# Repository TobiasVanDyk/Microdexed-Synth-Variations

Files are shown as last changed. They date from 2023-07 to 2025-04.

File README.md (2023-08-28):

# Microdexed and Minidexed Synth Variations

Variations of the Microdexed FM Synth by [**Codeberg-dcoredump**](https://codeberg.org/dcoredump/MicroDexed) - using a PCM5102A module, and 6N137 for the Midi input, and Microdexed Touch FM Synth by [**Codeberg-positionhigh**](https://codeberg.org/positionhigh/MicroDexed-touch) - it replaced the 2.8 inch LCD with a 3.2 inch sized LCD, used full-sized Midi in and out sockets, and a 6N137 for the Midi input.

In addition four Circle-based Raspberry Pi synths were made: Three Raspberry Pi 3B+ and 3B synth variations of the **miniDexed FM Synth** (which is an 8 x DX7) synth, by [**Probonopd**](https://github.com/probonopd/MiniDexed), two using a using a Waveshare WM8960 DAC Hat and one with a PCM5102A DAC module, and all three with a 6N137 MidiIn DIN socket, and one with a Pico PC USBMidi Interface. A fourth **MT32-Pi** synth using a Raspberry 3A+ and WM8960 DAC was assembled on a breadboard.

The [**Zynthian Open Synth Platform**](https://zynthian.org/) also use both the [**Dexed**](https://zynthian.org/engines/_engine-list/engine-dexed) (Microdexed and Minidexed) and [**Fluidsynth**](https://zynthian.org/engines/_engine-list/engine-fluidsynth) (MT32-Pi) synth engines, but is based on a more traditional low-latency, almost RT, operating system, similar to [**Patchbox OS**](https://blokas.io/patchbox-os/).
 
<p align="left">
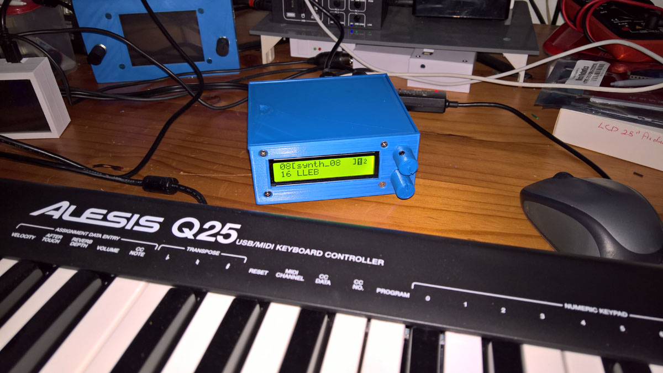
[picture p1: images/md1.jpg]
 
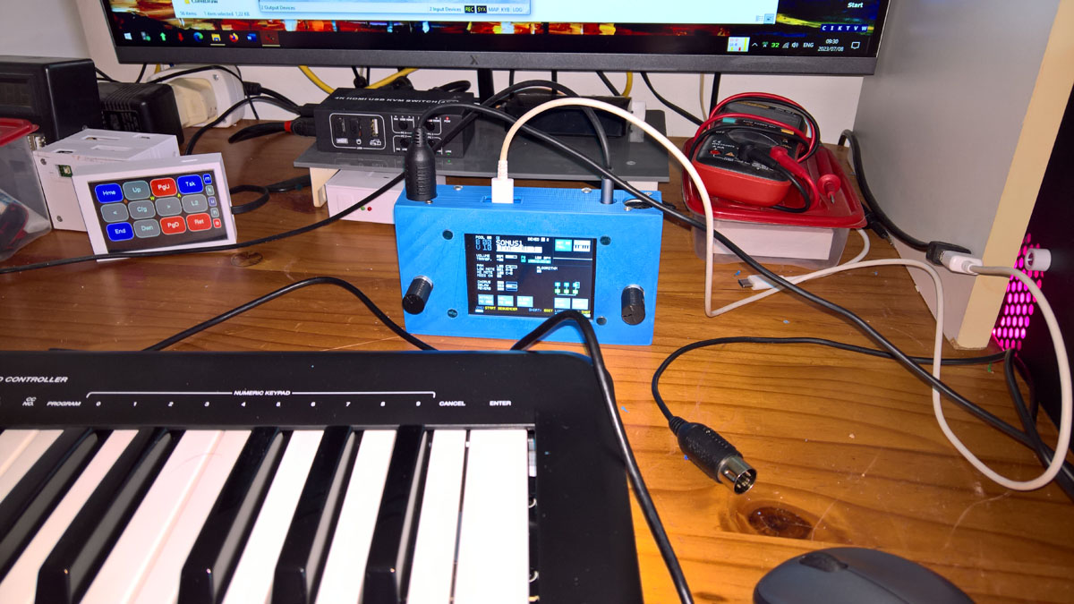
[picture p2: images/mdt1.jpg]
 
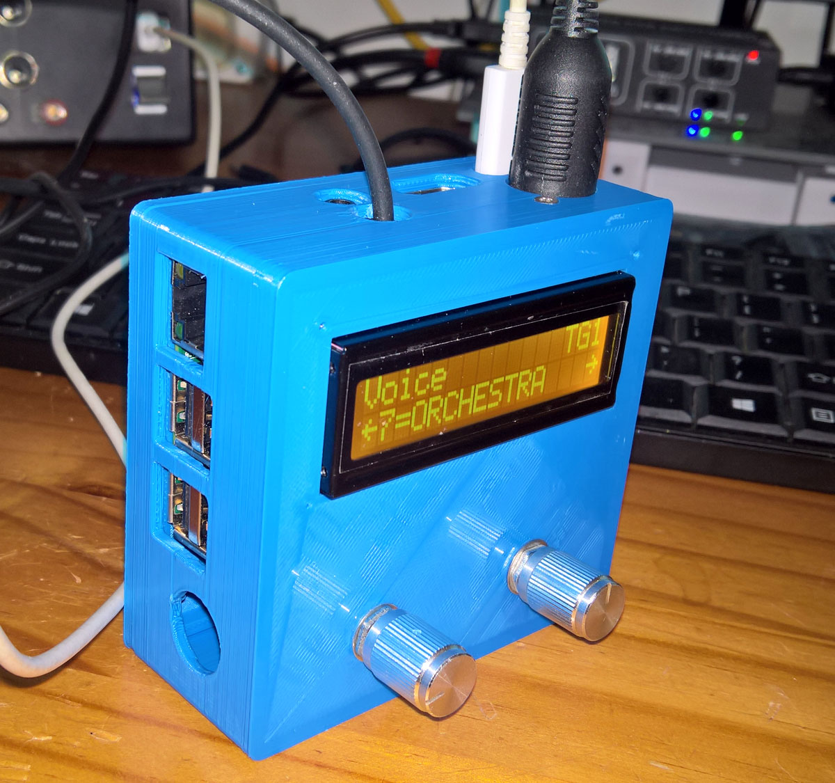
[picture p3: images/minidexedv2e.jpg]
  
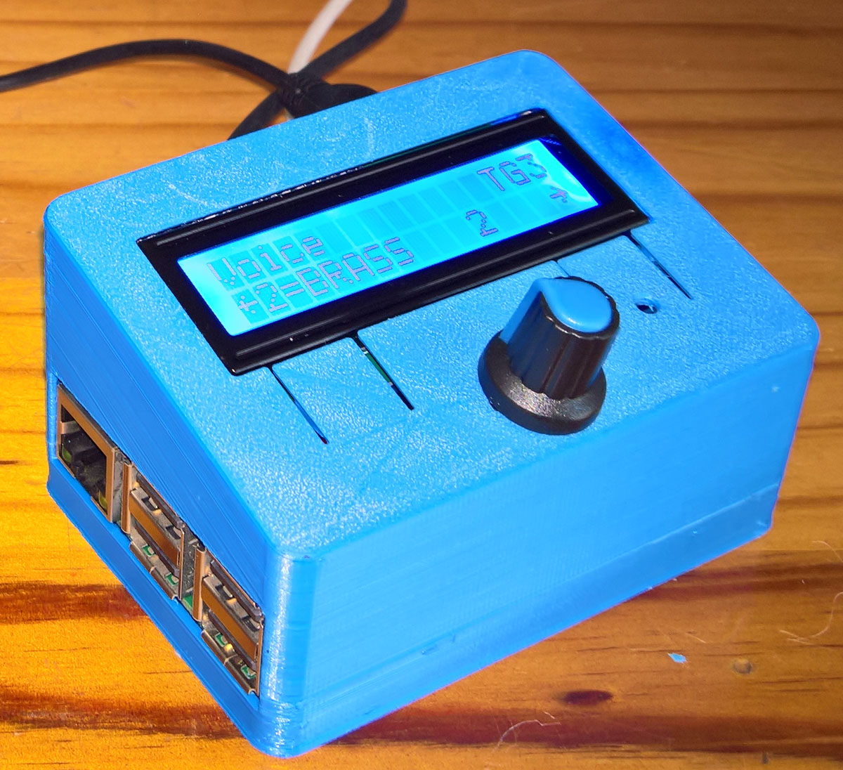
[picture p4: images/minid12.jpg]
  
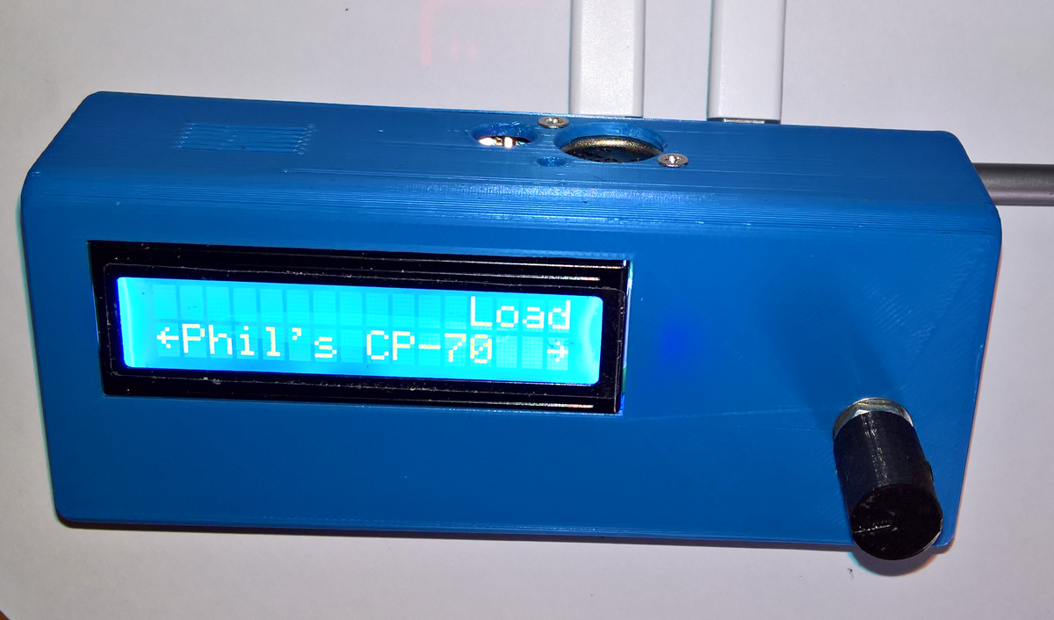
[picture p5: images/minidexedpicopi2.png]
    
</p>

* [**Microdexed FM Synth Teensy 3.6 Variation**](Microdexed1)

* [**MicrodexedTouch FM Synth Teensy 4.1 Variation**](Microdexed2)

* [**Microdexed FM Synth Teensy 4.0 and Teensy 4.1 Dev-branch Variation**](Microdexed3)

* [**Minidexed FM and MT32-Pi Raspberry Pi 3B+ and 3A+ and WM8960 DAC Circle-based Synths**](Minidexed1)

* [**Compiling Minidexed under WSL2 (Ubuntu 20.04) on Windows 11**](https://github.com/TobiasVanDyk/Microdexed-Synth-Variations/tree/main/Minidexed1/Minidexed-compile-WSL2-Win11)

* [**Minidexed Raspberry Pi 3B and Pico RP2040 USBMidi Interface and PCM5102A DAC Synth**](Minidexed2)

* [**Pico RP2040 USBMidi PC Interfaces for the Minidexed Synth**](PicoUSBMidi-PCInterface)

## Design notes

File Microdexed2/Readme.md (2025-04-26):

# Microdexed-Touch: Teensy 4.1 - PCM5102A DAC - 3.2inch ILI9341 Resistive Touch LCD - 6N137 Midi-In

This is a variation of the Microdexed Touch FM Synth (Yamaha-DX7) by [**Codeberg-positionhigh**](https://codeberg.org/positionhigh/MicroDexed-touch). It replaced the capactive touch 3.2 inch LCD with a resistive touch LCD, uses full-sized Midi in and out sockets with a 6N137 for the Midi input. Compiled versions 1.9.8.7 (16 MB PSRAM) and 1.7.1 (8 MB PSRAM 16 MB Flash), firmware was used. 

Both firmware versions are shown below, the stripboard layout for both are the same as only the Flash module is removed from its socket on the stripboard, and a second 8MB PSRAM module was soldered on the back of the Teensy 4.1. The .hex firmware for the two versions are in the folders PSRAM8-Flash-v171 and PSRAM16-v1987. Replace platformio.ini and config.h with those included in the folders if new versions are compiled.

The stripboard Fritzing layout is included here, as are the case 3d-files. Refer to the photo included in the [**issue here**](https://github.com/TobiasVanDyk/STM32F411-PCM5102A-24bit-USB-Audio-DAC/issues/2) for how to bridge three of the DAC module option pads.

The older schematic for a resistive touch LCD is shown below for the new schematic refer to the [**March 2025 build manual**](https://codeberg.org/positionhigh/MicroDexed-touch/wiki/BUILD-AND-USER-MANUAL)

<p align="left">
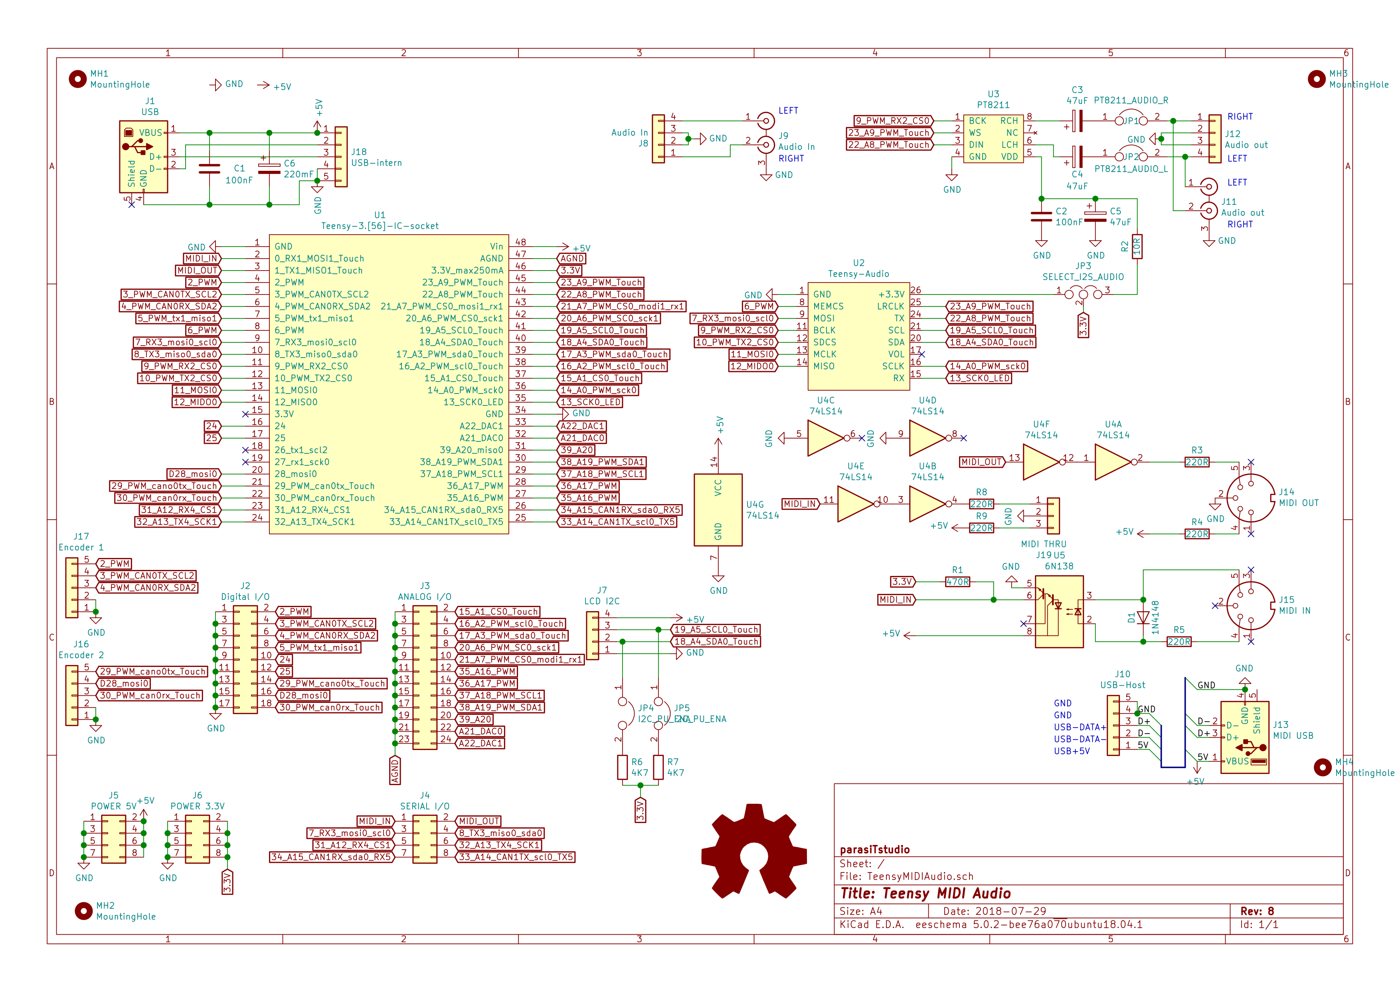
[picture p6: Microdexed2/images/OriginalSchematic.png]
 
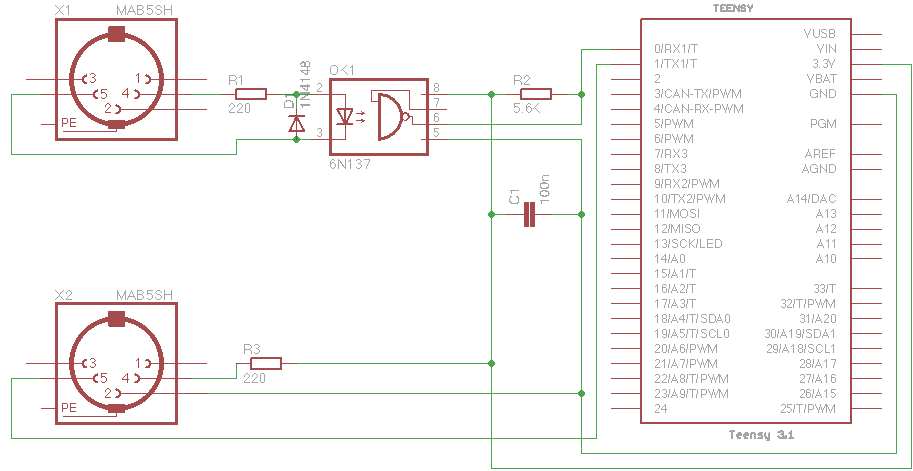
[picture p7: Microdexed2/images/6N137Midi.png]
 
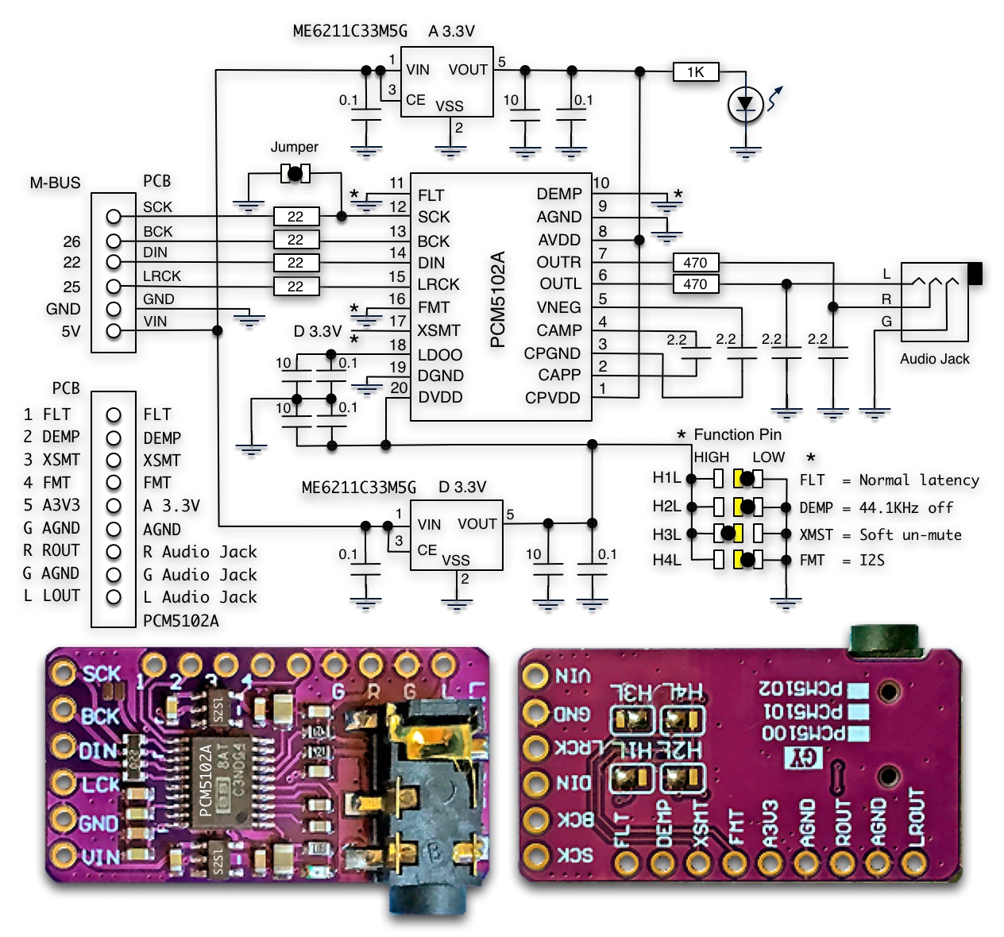
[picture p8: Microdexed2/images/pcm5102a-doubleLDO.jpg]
 
</p>

<p align="left">
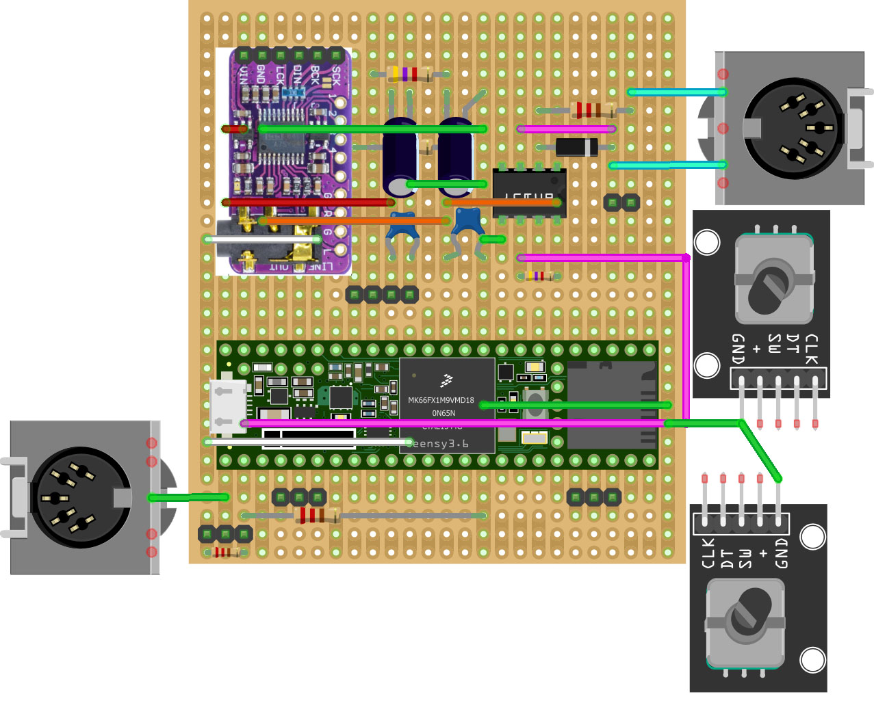
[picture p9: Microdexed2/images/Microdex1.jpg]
 
 
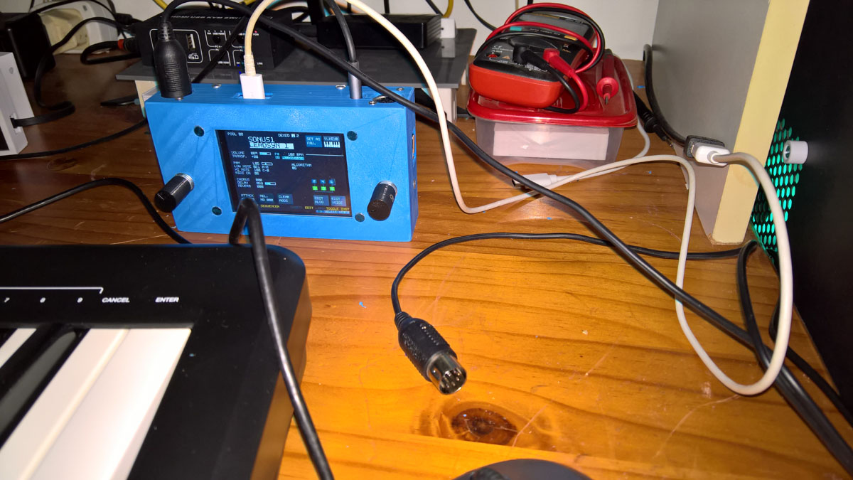
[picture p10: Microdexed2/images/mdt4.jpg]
 
</p>

<p align="left">
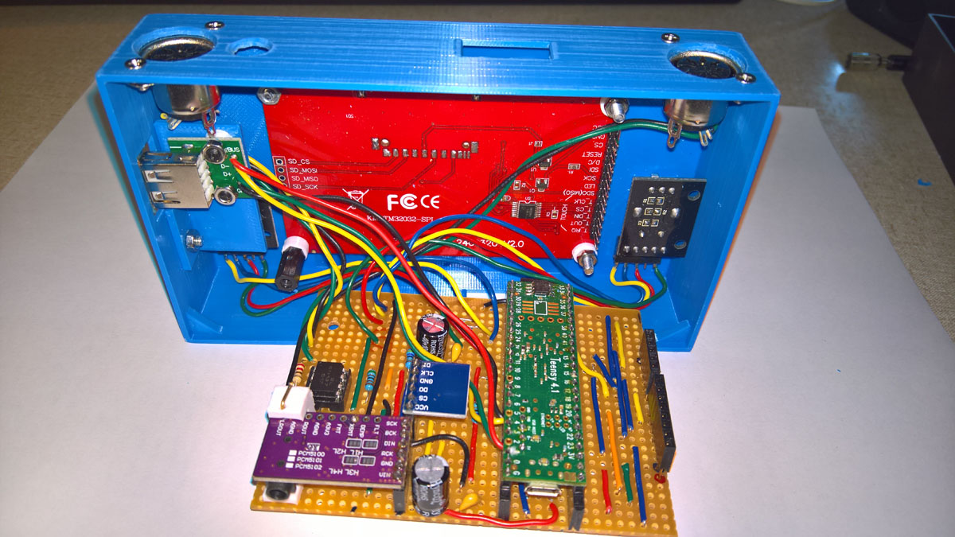
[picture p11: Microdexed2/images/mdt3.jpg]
 
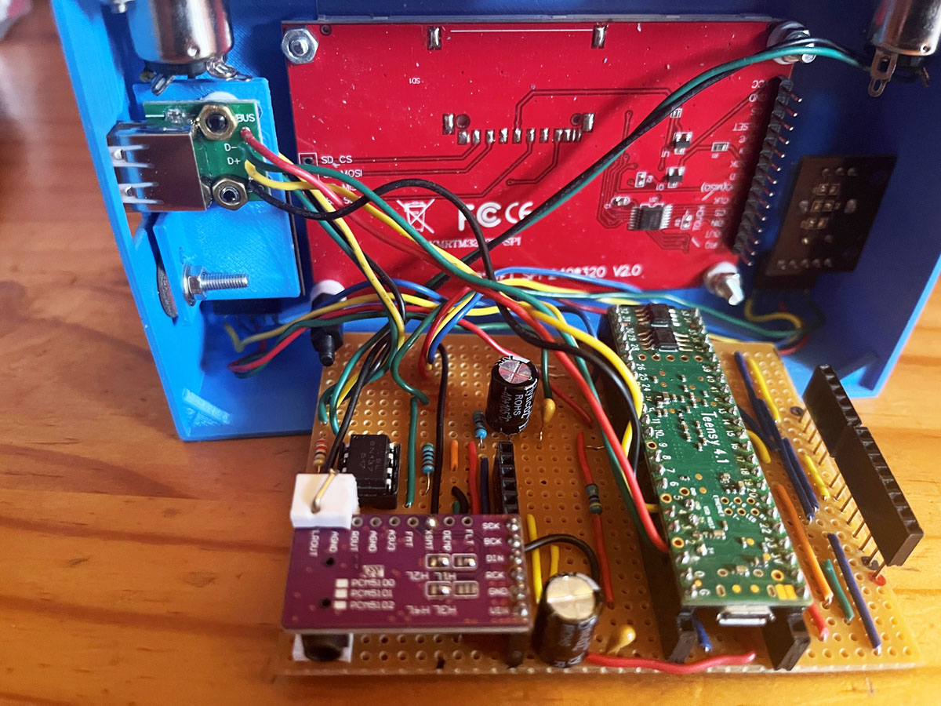
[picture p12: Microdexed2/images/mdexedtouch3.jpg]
 
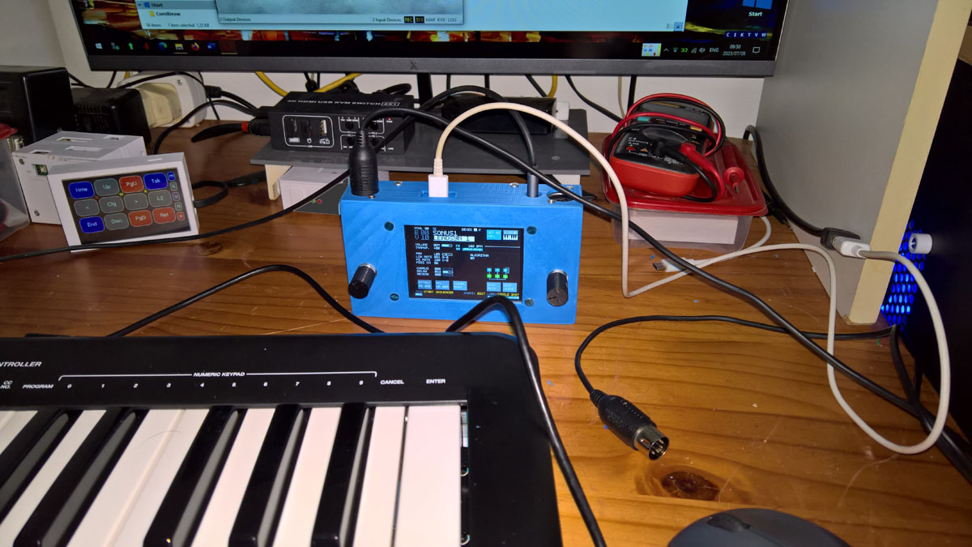
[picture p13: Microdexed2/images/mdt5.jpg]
 
</p>

Note the warning when [**using i2c Backpacks with 5v LCD displays and 3v3 MCU's or Raspberry Pi's**](https://github.com/TobiasVanDyk/Microdexed-Synth-Variations/tree/main/i2cbackpack)

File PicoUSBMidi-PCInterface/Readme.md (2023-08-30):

## Pico RP2040 as USB Midi PC Interface for the Raspberry Pi Minidexed

Three different PC USB-Midi Interfaces were compiled and tested as a means to connect the Minidexed RaspberryPi 3B to a PC as a Midi Synth device. Two are Pico-SDK-based and the third is Arduino IDE-based. All three worked well and will be expanded on in the future. Currently the neatly-coded Midi-Adapter by rsta2 is installed in the Minidexed Synth referred to here as Minidexed2.

* **USB-Midi Interfaces 1 and 2:** These are Pico SDK-based and are from the same [**rsta2 Github**](https://github.com/rsta2/pico) as the Circle libraries. Both were compiled on Windows 10 using the [**instructions available here**](https://github.com/TobiasVanDyk/Pico-MCU-from-Raspberry-Pi/blob/main/Install-Pico-SDK-in-Windows10x64-May-2023.pdf), and both the build directories and the uf2 files are here as Midi-Adaptor.zip. Both interfaces were connected using the Pico's UART0-TX (Pin1) and 3v3 (Pin36) via two 47ohm resistors to a 6N137 optical 5Pin Midi DIN input (in turn connected the the Raspberry Pi's Rx pin). Alternatively they were connected via the Pico GND (Pin3) and TX0 (Pin1) directly to the raspberry Pi's RX Pin. Midi-Ox shows Midi-Adaptor-Flex as having one input and one output - refer to the picture below. (The Um ONE adapter is a Roland UM-One Mk2)

* **USB-Midi Interface 3:** This is [**based on the discussion here**](https://www.reddit.com/r/raspberrypipico/comments/11w8f29/multiple_virtual_usb_midi_cables_using_arduino_ide/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), and the code presented there were compiled using the Earle-Philhower Arduino IDE setup. The ino and uf2 files are here as DualInOutUSBMidi.zip. This is still a WIP and will be looked at in more detail later, but it is is working with the Minidexed Synth. Midi-Ox shows it as having two inputs and two outputs - refer to the picture below. Both inputs were tested with the Minidexed Raspberry Pi using TX0 and TX1 respectively ie. connected to the Minidexed through the Pico's TX0 (Pin1) and TX1 (Pin6) and 3v3 using 47ohm resistors on both wires. 

There are two ways to connect the Pico to the Minidexed Raspberry Pi. The first is through the (added) Midi optical 6N137 interface using the Pico TX (Pin1) and 3v3 (Pin36) Pins via two 47ohm resistors. The second is to connect the Pico TX0 and Ground directly to the Raspberry Pi's RX (Pin10) and Ground (Pin6) connection. The latter option is used here and a SPDT switch selects between the 6N137-Midi or the Pico-USBMidiPC input to the Minidexed Synth. The picture below shows the Pico USMMidi Interface installed in the Minidexed2, inbetween the PCM5102A DAC modile abd 6N137 Midi-Input on the left, and the Raspberry Pi 3B on the right. Currently the Pico and Raspberry Pi are independantly powered but if the Pico is permantly used the Raspberry Pi could be powered from the Pico's VSys 5v pin. 

<p align="left">
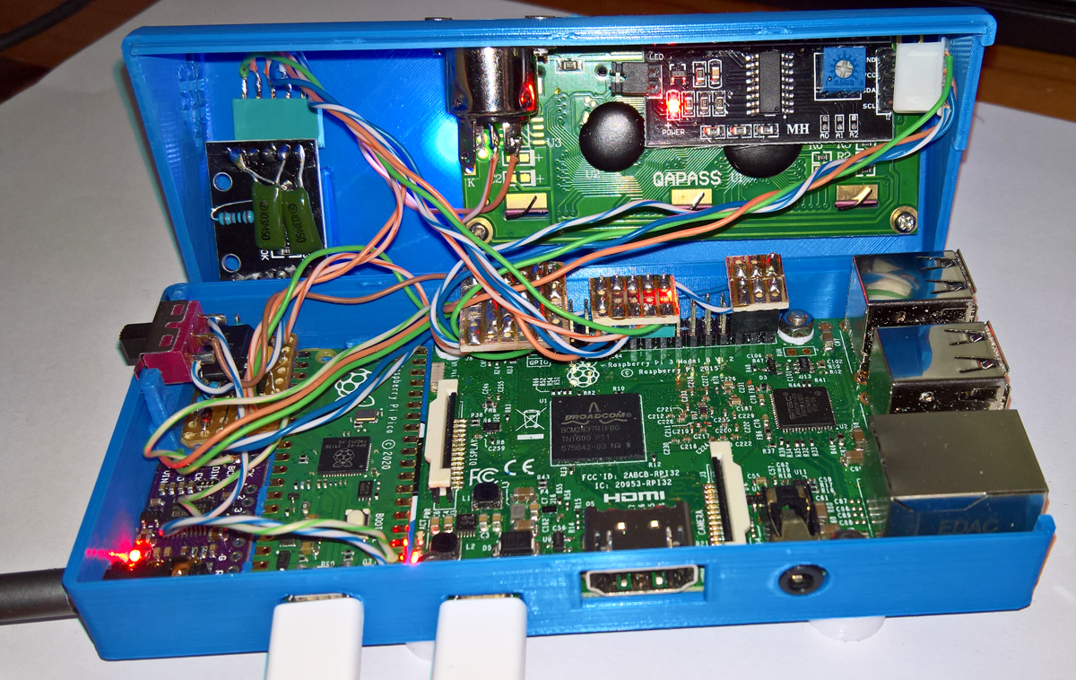
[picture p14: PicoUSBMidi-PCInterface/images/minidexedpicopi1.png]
 
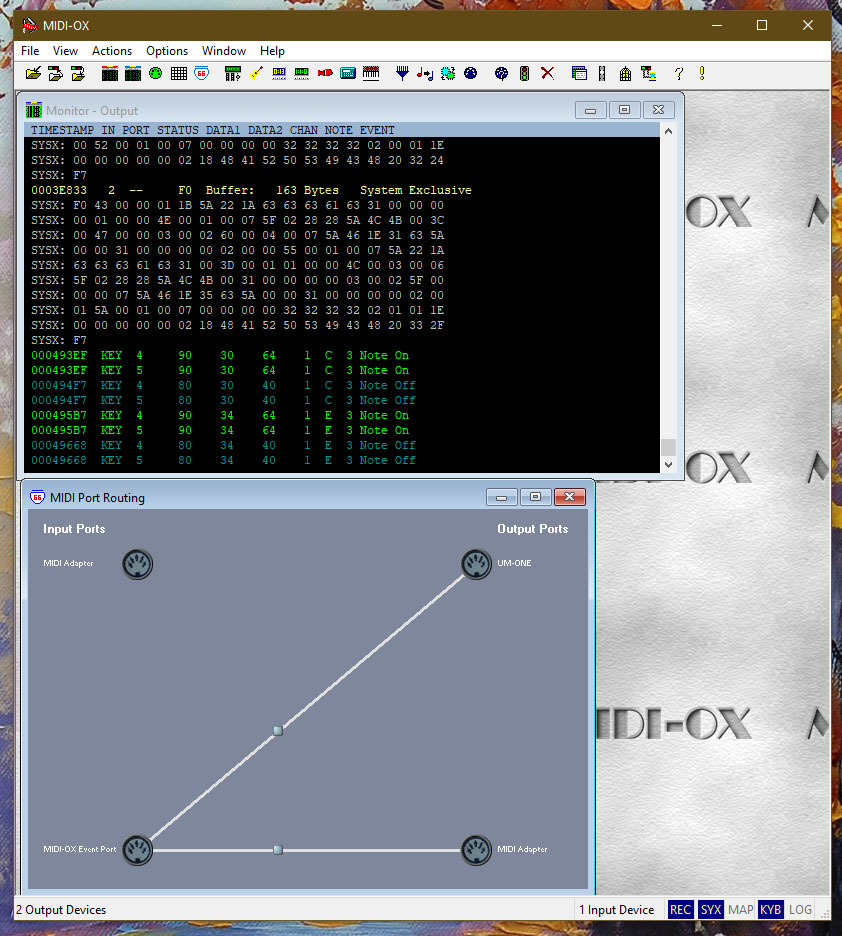
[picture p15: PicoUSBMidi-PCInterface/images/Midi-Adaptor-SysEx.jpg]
 
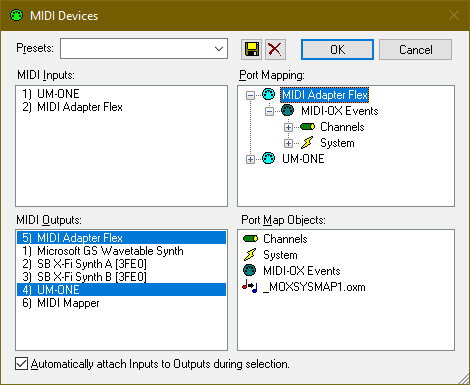
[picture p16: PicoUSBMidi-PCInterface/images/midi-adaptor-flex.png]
 
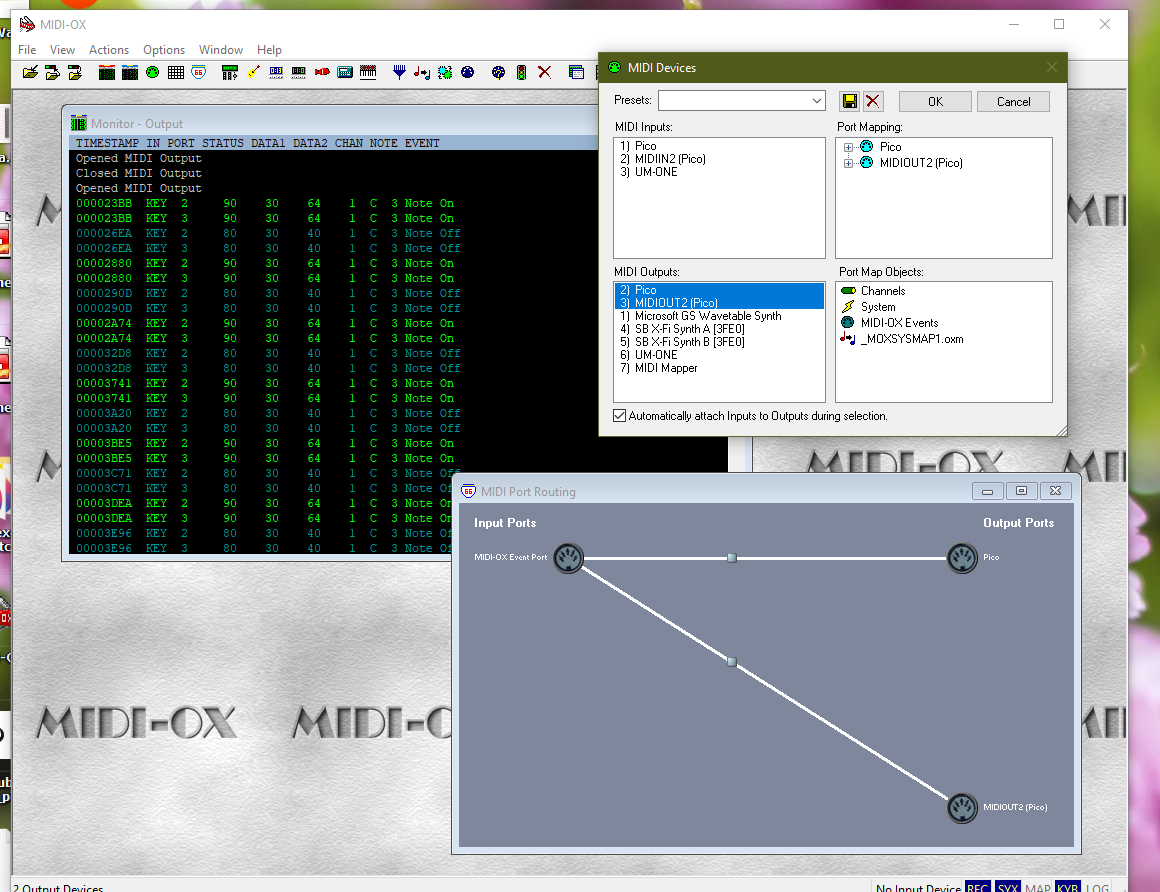
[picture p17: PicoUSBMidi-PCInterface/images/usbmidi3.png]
 
</p>

There is also an fourth option to use Circuitpython the make the Pico-based Midi interface - this was not tested but is [**discussed here**](https://github.com/alf45tar/PedalinoMini) just after the rsta2 SDK -based interface. [**This site has many Pico Midi interface and router projects**](https://diyelectromusic.wordpress.com/) mainly using Circuitpython. 

Another site use a Pico USB Host to bridge a modern USB MIDI device such as a Midi Music keyboard to a 5-pin DIN MIDI IN and MIDI OUT - [**midi2usbhost**](https://github.com/rppicomidi/midi2usbhost), and a Pc USB to 5-pin DIN MIDI interface - [**midi2usbdev**](https://github.com/rppicomidi/midi2usbdev), also using a Pico. This has not been tested as yet.

* **SDK compile instructions:** Download [**rsta2 Pico**](https://github.com/rsta2/pico) as a zip file and extract under your Pico development folder as a folder pico. Open a Developer Command Prompt Window (Visual Studio Shell) as administrator, and (for example) run: setx PICO_SDK_PATH "C:\Users\Pico\Downloads\pico-sdk" or wherever your own Pico SDK is situated. Then do:
 
``` 
cd pico
mkdir build
cd build
cmake -G "NMake Makefiles" ..
nmake
``` 

This will build all four of the example projects - the uf2 files are inside the build directories.

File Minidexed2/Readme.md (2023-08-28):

# Minidexed with Pico USBMidi Interface for a Minidexed Raspberry Pi 3B

**This is a Minidexed with Raspberry Pi 3B using a PCM5102A module, a Pico RP2040 PC USBMidi-Interface, and a 6N137 Midi 5pin DIN Input**

This is another variation of the Minidexed DX7-Synth by [**Probonopd**](https://github.com/probonopd/MiniDexed) and [**Circle**](https://github.com/rsta2/circle) which runs the RPi as a if it is an MCU. 

It uses the excellent [**snap-close**](images/DHSbuild.png) 3d-printed case [**presented by dhstsw here**](https://github.com/probonopd/MiniDexed/discussions/165), and the top and modified bottom (the trimpot was replaced with a [**6N137 Midi Interface**](6N137Midi.png) and a 5pin DIN socket added) STL files are in the STL folder. The modified case here is still a WIP. 

The Pico and Minidexed Tx-Rx Midi interface is [**discussed here**](https://github.com/TobiasVanDyk/Microdexed-Synth-Variations/tree/main/PicoUSBMidi-PCInterface).

<p align="left">
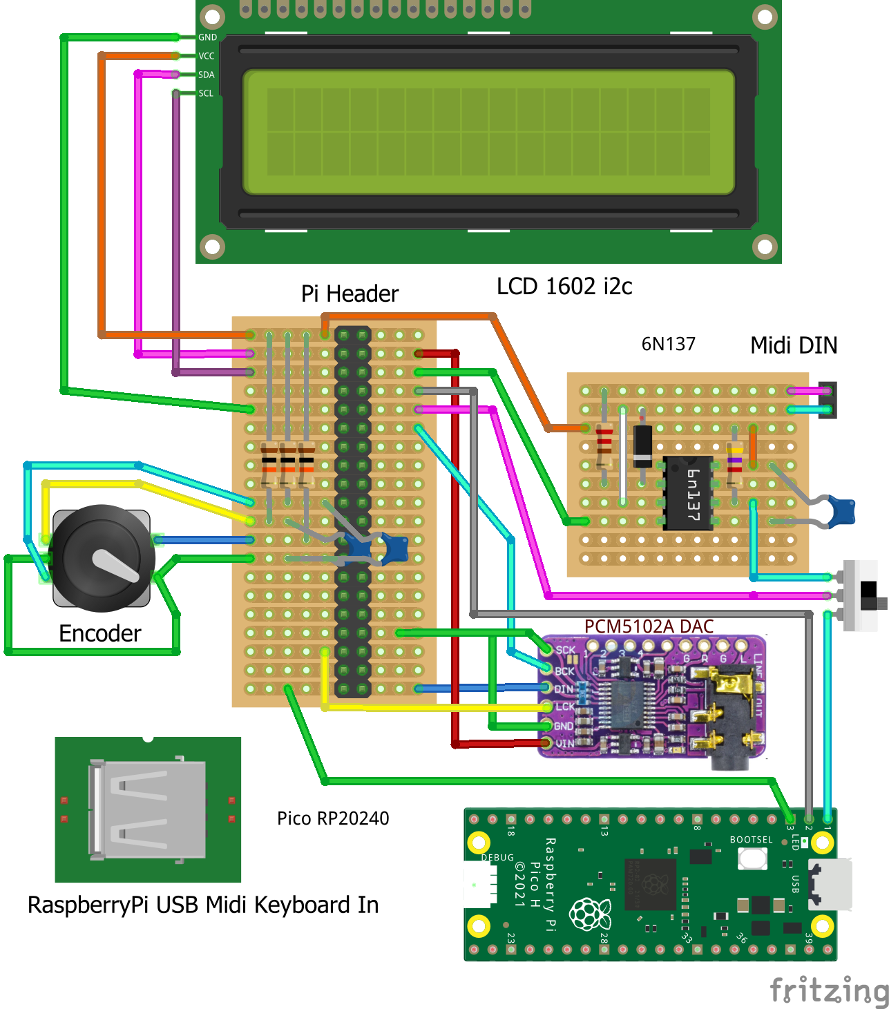
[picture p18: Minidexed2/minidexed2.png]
   
 
 
</p>

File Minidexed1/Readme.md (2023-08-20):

# Minidexed with Raspberry Pi 3B+ and MT32-Pi with a Raspberry Pi 3A+

## Minidexed with Raspberry Pi 3B+ using a Waveshare WM8960 DAC hat and a 6N137 MidiIn
This is variation of the Minidexed 8xDX7 (Yamaha-DX7-Synth) by [**Probonopd**](https://github.com/probonopd/MiniDexed) and [**Circle**](https://github.com/rsta2/circle) which runs the RPi as a if it is an MCU. (Circle is a C++ bare metal programming environment for the Raspberry Pi - i.e. it is not a RTOS.)

Two case variations were used. The first used the the snap-close 3d-case made available at the Github Minidexed site, and the second was based on a [**Minidexed case**](https://github.com/probonopd/MiniDexed/discussions/165) by [**RomixNL on Thingiverse**](https://www.thingiverse.com/thing:5371115). The STL files for the modified RomixNL case are in the STL folder here. The second rotary encoder present in the the second case will be used as a volume control and mute (all notes off) control.

In both cases two changes were made: (1) This uses the i2s + i2c [**Waveshare WM8960 DAC**](https://www.waveshare.com/wm8960-audio-hat.htm) as [**discussed here**](https://github.com/TobiasVanDyk/RaspberryPi-GPIO-Audio) and [**here**](https://github.com/TobiasVanDyk/Wolfson-WM8960-Arduino-Teensy-Driver), and sounds great. (2) A [**DIN 6N137 Midi-In**](images/6N137Midi.png) was also added. A list of the [**hardware and build intructions**](https://github.com/probonopd/MiniDexed/wiki/Hardware) are presented in detail on the Minidexed Github. 

The Minidexed can be used as a USB Midi host i.e. it can play via a Midi USB keyboard plugged into the Minidexed Raspberry Pi USB ports, but needs something such as a ATMega32U4 (Arduino Pro Micro) or RPi Pico, to act as a a USB Midi device i.e. appear to a PC as a [**USB Midi device**](https://github.com/probonopd/MiniDexed/discussions/236).

It should be noted that the 3v3 regulator on the Pi3B(+)/4B can easily supply the 1602LCD current (about 80mA) - refer to [**this discussion**](https://raspberrypi.stackexchange.com/questions/51615/raspberry-pi-power-limitations) where a value of 800mA maximum for the 3v3 supply is suggested.

<p align="left">
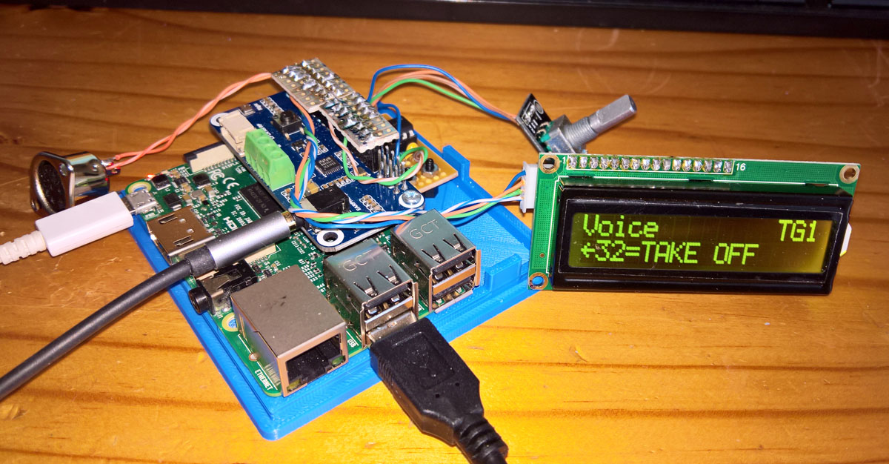
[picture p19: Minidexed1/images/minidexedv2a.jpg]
 
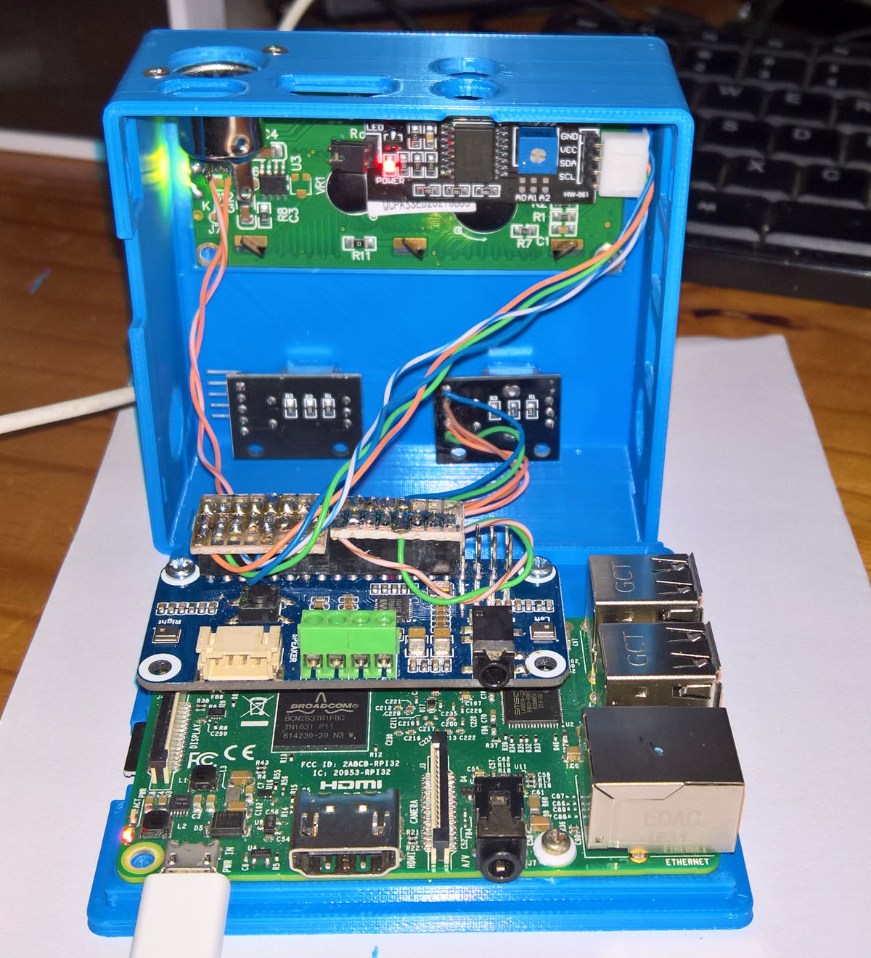
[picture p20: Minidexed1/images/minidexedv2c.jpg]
 
</p>

<p align="left">
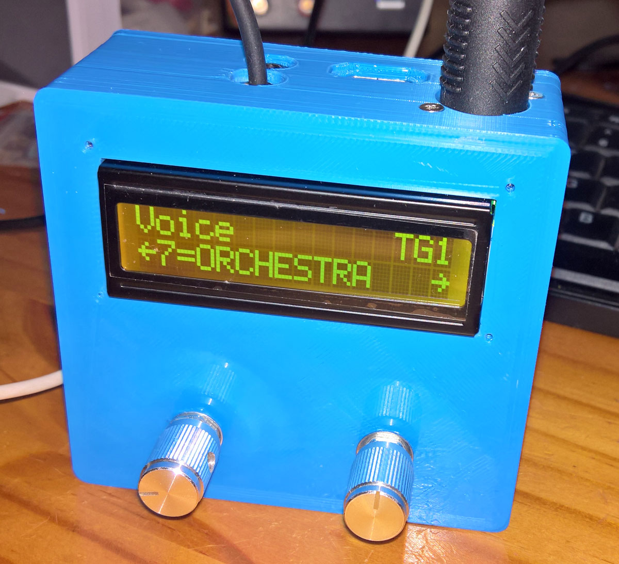
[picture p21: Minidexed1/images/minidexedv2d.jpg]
 
 
</p>

<p align="left">
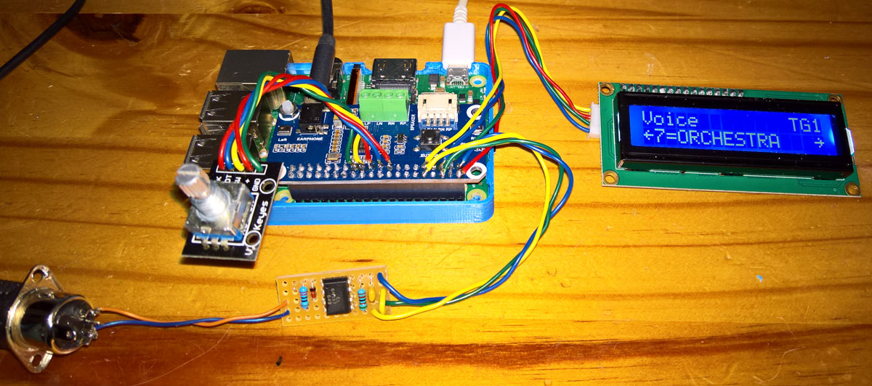
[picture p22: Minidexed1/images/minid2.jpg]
 
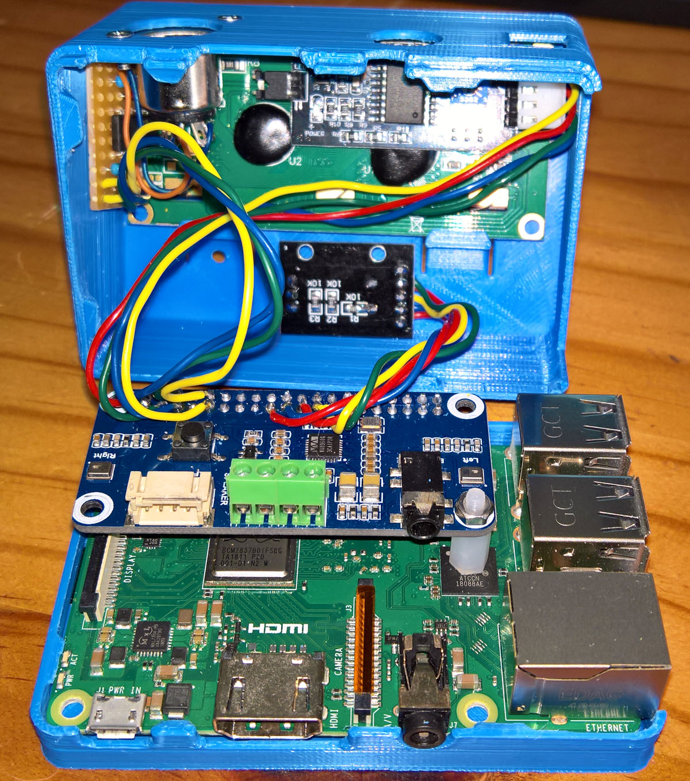
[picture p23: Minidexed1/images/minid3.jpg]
 
</p>

<p align="left">
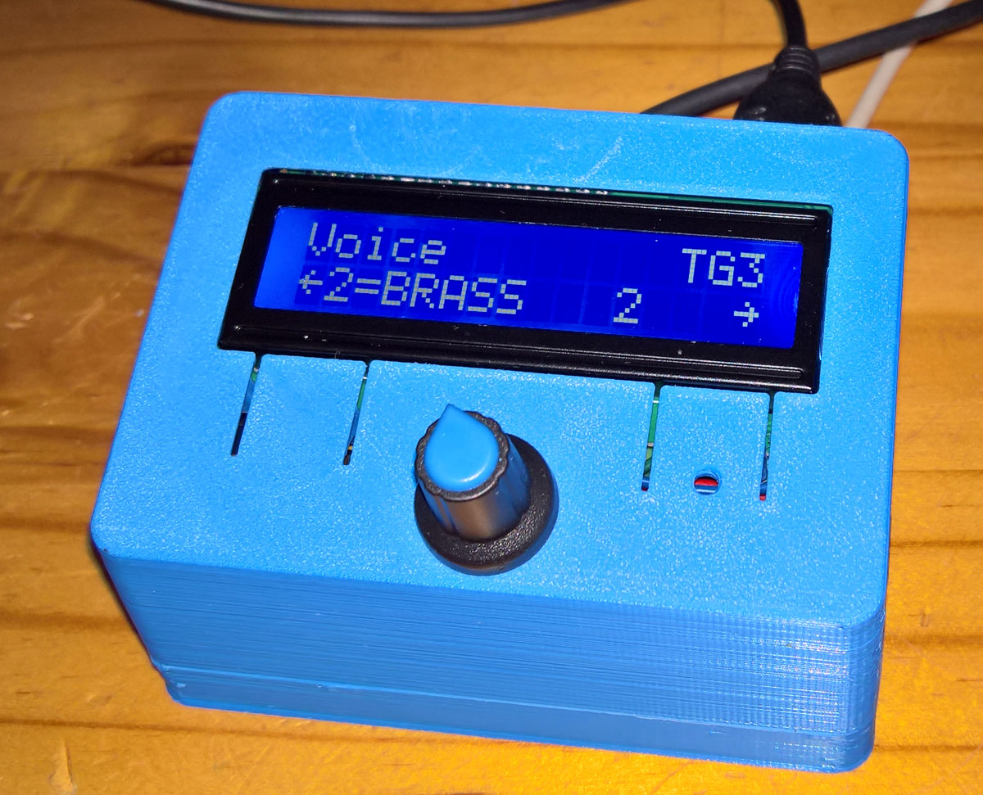
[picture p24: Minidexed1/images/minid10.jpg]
 
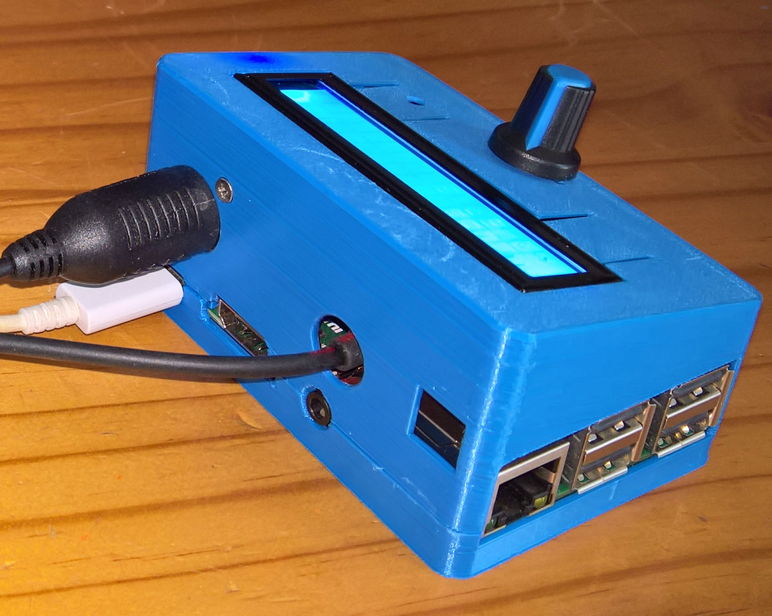
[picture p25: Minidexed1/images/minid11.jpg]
 
 
</p>

## MT32-Pi with a Raspberry Pi 3A+ using a Waveshare WM8960 DAC hat and an SH1106 128x64 OLED display and a 6N137 MidiIn
The [**MT32-Pi**](https://github.com/dwhinham/mt32-pi) Roland-MT32, similarly runs on Circle, and is also a baremetal MIDI synthesizer (for a Raspberry Pi 3 or above), based on Munt and FluidSynth, but the interface needs further development. It is currently only constructed on breadboard and used a Raspberry Pi 3A+, and the same WM8960 DAC but used an SH1106 OLED 128x64 display. The mt32-pi.cfg used is included here.

<p align="left">
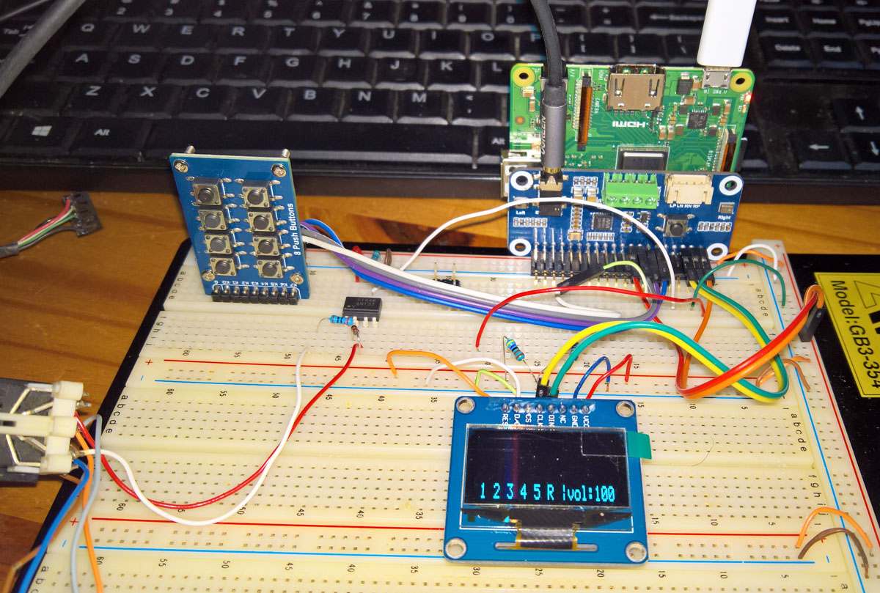
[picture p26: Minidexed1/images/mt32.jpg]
 
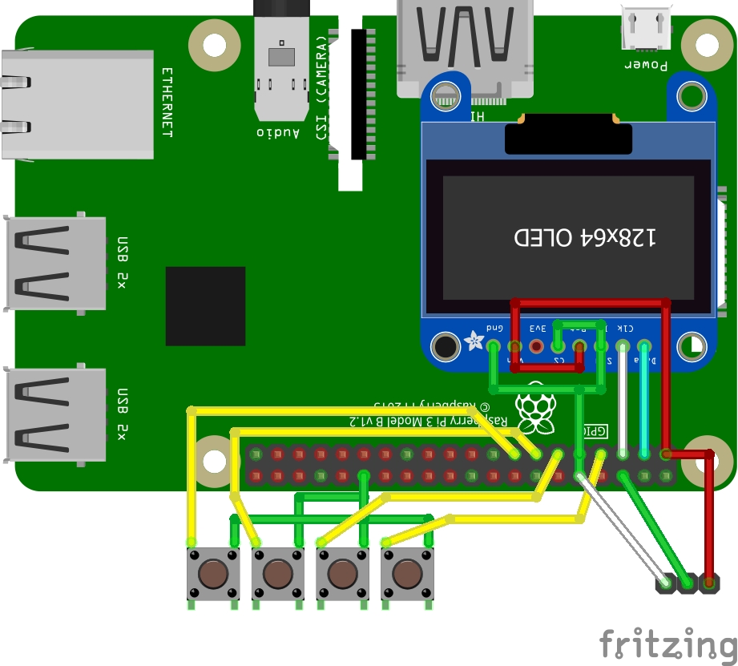
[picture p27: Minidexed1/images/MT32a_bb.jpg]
   
</p>

Note the warning when [**using i2c Backpacks with 5v LCD displays and 3v3 MCU's or Raspberry Pi's**](https://github.com/TobiasVanDyk/Microdexed-Synth-Variations/tree/main/i2cbackpack)

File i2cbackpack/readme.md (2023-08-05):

## Using i2c Backpacks with 5v LCD displays and 3v3 MCU's or Raspberry Pi's

When using a 5v LCD 1602 character display remove the two two SMD 4k7 resistors to the lower left of the IC - they are on the I2C Interface that pulls SDA and SCL up to 5v - and then add external resistors that pull them up to 3v3 when using these 5v displays with a Teensy 3.6, 4.0 or 4.1, or with a Raspberry Pi - see the before and after photos below. It may also be necessary to insert a 1N4148 in the LCD +5v line.

This is also mentioned here: [**16x2 LCD**](https://github.com/probonopd/MiniDexed/wiki/Hardware#usb-midi-device)
*LCD1602 display or similar.  So you can get a display with or without an i2c "backpack" board. An an i2c "backpack" board greatly simplifies the setup because fewer physical connections need to be made.*

***WARNING: Simpler backpacks are designed to be powered by 5V and include pull-up resistors on the I2C bus to 5V too. If you have one of these you will need a 3V3 to 5V level shifter to avoid pulling up the Pi's I2C GPIO pins to 5V! Alternatively it may be possible to remove (desolder) the built-in pull-ups to 5V and add new ones to 3V3. If you're not sure what kind you have, power the LCD from 5V and GND only and measure the voltage on the I2C pins to see if it is 5V or 3V3. Non-backpack LCDs, whilst still powered by 5V, are only connected to Pi GPIO outputs, so driving them at 3V3 from the Pi is fine.***

Another solution leaves the 4k7 pullup resistors but add two 10k resistors to ground to form a 5v x 2/3 voltage divider - refer to the discussions [**here**](https://github.com/probonopd/MiniDexed/discussions/373) or [**here**](https://forums.raspberrypi.com/viewtopic.php?t=88399).

The [**discussion above**](https://github.com/probonopd/MiniDexed/discussions/373) also examines the i2c address settings for the two PCF8574 variants - refer to the two tables below.

<p align="left">
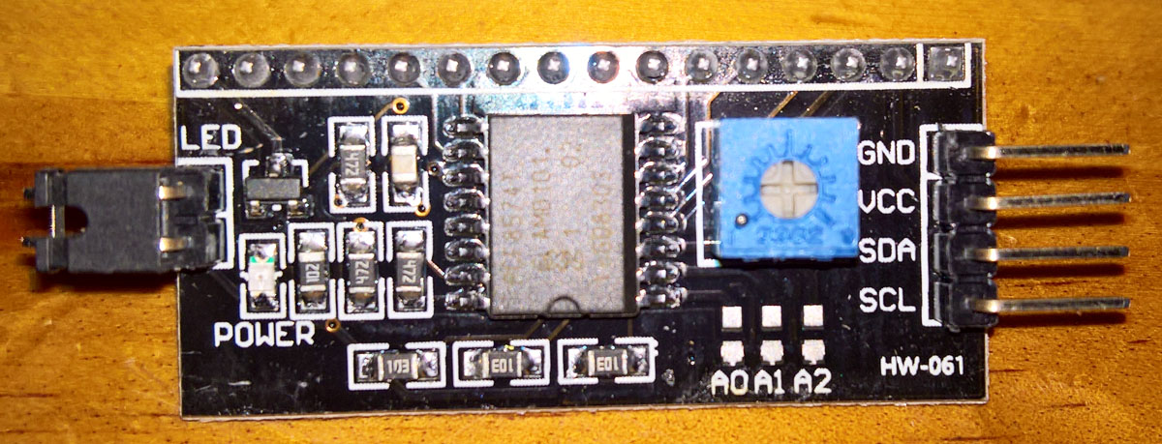
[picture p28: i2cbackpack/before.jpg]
 
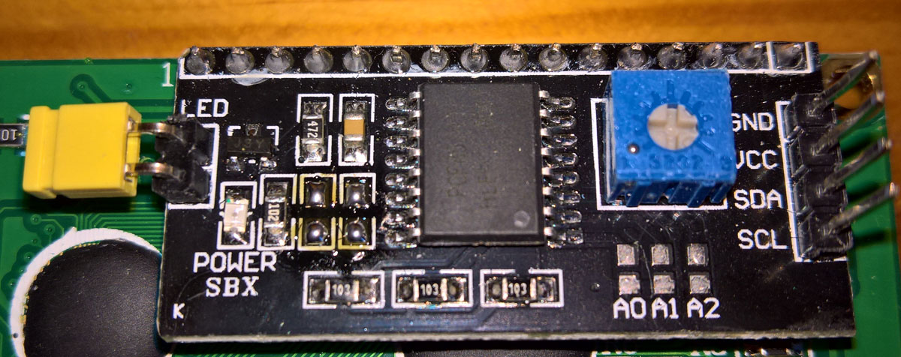
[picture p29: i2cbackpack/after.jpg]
 
</p>

<p align="left">
 
 
   
</p>

<p align="left">
 
 
</p>

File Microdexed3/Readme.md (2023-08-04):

# Microdexed with Teensy 4.0 and 4.1

## Microdexed with Teensy 4.0 and PCM5102A and 16x2Character i2c LCD and a 6N137 Midi In
This is variation of the standard branch of the MicroDexed 6-operator-FM-YanahDX7-Synth by [**Codeberg-dcoredump**](https://codeberg.org/dcoredump/MicroDexed). It replaced the Teensy Audio board with an inexpensive PCM5102A module, and used a 6N137 for the Midi input. Changes made to the config.h file are included here, and the firmware hex file that can be uploaded to this Teensy 4.0 synth using the Teensyloader are also included here.

It is currently constructed on a breadboard and the connections between the Teensy 4.0 and the [**SDCard module Front**](images/SDCard.png) and [**Back**](images/SDCardBack.png), the two encoders, the PCM5102A DAC and the LCD are given in [**Connections.txt**](Connections.txt). The changed DAC connections are not described in config.h and had to be traced from a [**Teensy 4.1 to teensy 3.6 adapter board**](images/T41-Adapter-Board.jpg) from [**another repository**](https://codeberg.org/dcoredump/TeensyMIDIAudio/src/branch/master/T4.1-Adapter-Board). The USB Host connection (D- and D+) for a USB Midi Keyboard are taken from the two bottom pads underneath the Teensy 4.0.

<p align="left">
 
 
 
</p>

## Microdexed with Teensy 4.1 with 8MB PSRAM and Audioboard Rev D  and 16x2Character i2c LCD and a 6N137 Midi In
This is variation of the development branch of the MicroDexed 6-operator-FM-YanahDX7-Synth by [**Codeberg-dcoredump**](https://codeberg.org/dcoredump/MicroDexed/src/branch/dev).  The full set of libraries and the changes made to the config.h file are included here, and the firmware hex file that can be uploaded to this Teensy 4.1 synth using the Teensyloader are also included here. It is currently constructed on a breadboard.

<p align="left">
 
</p>

Note the warning when [**using i2c Backpacks with 5v LCD displays and 3v3 MCU's or Raspberry Pi's**](https://github.com/TobiasVanDyk/Microdexed-Synth-Variations/tree/main/i2cbackpack)

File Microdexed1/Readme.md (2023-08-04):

# Microdexed with Teensy 3.6 and PCM5102A and 16x2Character i2c LCD and a 6N137 Midi In

This is a variation of the MicroDexed 6-operator-FM-YanahDX7-Synth by [**Codeberg-dcoredump**](https://codeberg.org/dcoredump/MicroDexed). It replaced the (recommended) Teensy Audio board with an inexpensive PCM5102A DAC module, and used a 6N137 for the Midi input. The changes made to the config.h file are included here. Also include here is the firmware (hex file) used that can be uploaded to the Teensy 3.6 using the Teensyloader.

What was immediately strinking is how quiet this synth is - no digital noise is audible. The Teensy 3.6 was chosen instead of the Teensy 4x because it is likely that the two Teensy 3.6 12-bit DACs will programmed as a CV output controls in the future.

It is constructed on stripboard and a Fritzing layout is included here, as are the 3d-files for the case. 

<p align="left">
 
 
 
</p>

<p align="left">
 
 
 
</p>

<p align="left">
 
 
 
</p>

Note the warning when [**using i2c Backpacks with 5v LCD displays and 3v3 MCU's or Raspberry Pi's**](https://github.com/TobiasVanDyk/Microdexed-Synth-Variations/tree/main/i2cbackpack)

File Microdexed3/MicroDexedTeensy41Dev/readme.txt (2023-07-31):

This has PSRAM working with Teensy 4.1 and Audiobard 4 and 6N137 Midi In and USB host Midi Keyboard
Remember to take audio out from the lineout and not the headphone socket

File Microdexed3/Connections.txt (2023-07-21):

SDCard CS    Teensy 4.0 Pin 10
SDCard MOSI  Teensy 4.0 Pin 11
SDCard MISO  Teensy 4.0 Pin 12
SDCard SCK   Teensy 4.0 Pin 13
SDCard 3V3   Teensy 4.0 3V3

Encoder-Left Pin L Teensy 4.0 Pin 2
Encoder-Left Pin R Teensy 4.0 Pin 3
Encoder-Button L   Teensy 4.0 Pin 4

Encoder-Right Pin L Teensy 4.0 Pin 5
Encoder-Right Pin R Teensy 4.0 Pin 6
Encoder-Button R    Teensy 4.0 Pin 8

PCM5102A DAC DIN  Teensy 4.0 Pin 7
PCM5102A DAC BCK  Teensy 4.0 Pin 21
PCM5102A DAC LRCK Teensy 4.0 Pin 20
PCM5102A DAC 5V   Teensy 4.0 5V

LCD i2c SCL Teensy 4.0 Pin 19
LCD i2c SDA Teensy 4.0 Pin 18
LCD i2c 5V  Teensy 4.0 5V

LCD 320x240 Vcc    Teensy 4.0 5v
LCD 320x240 Gnd    Teensy 4.0 Gnd
LCD 320x240 CS     Teensy 4.0 Pin 15
LCD 320x240 Reset  Teensy 4.0 3V3
LCD 320x240 D/C    Teensy 4.0 Pin 9
LCD 320x240 SDI    Teensy 4.0 Pin 11 (MOSI)
LCD 320x240 SCK    Teensy 4.0 Pin 13
LCD 320x240 LED    Teensy 4.0 3V3
LCD 320x240 SDO    Teensy 4.0 Pin 12 (MISO)
LCD 320x240 TCLK   Teensy 4.0 Pin 13
LCD 320x240 TCS    Teensy 4.0 Pin 14
LCD 320x240 TCS    Teensy 4.0 Pin 13
LCD 320x240 TDI    Teensy 4.0 Pin 11
LCD 320x240 TOUT   Teensy 4.0 Pin 12
LCD 320x240 TIRQ   NC

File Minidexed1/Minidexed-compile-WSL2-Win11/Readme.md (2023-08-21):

# Compiling Minidexed under WSL2 (Ubuntu 20.04) on Windows 11

## Minidexed with Raspberry Pi 3B+ using a Waveshare WM8960 DAC hat and a 6N137 MidiIn
Using an updated Ubuntu 20.04 WSL2 on Windows 11 for compiling Minidexed was quick - a few minutes - but there are a few additional steps not mentioned on the [**Minidexed Wiki**](https://github.com/probonopd/MiniDexed/wiki/Development). The [**step discussed here**](https://github.com/probonopd/MiniDexed/discussions/269) was not needed.

A fresh WSL2 also needs:
``` 
sudo apt-get install build-essential
sudo apt install zip
``` 

You also need a Config.mk file with the content:
``` 
AARCH = 64
RASPPI = 3
PREFIX64 = aarch64-none-elf-
``` 

Copied to both ~/MiniDexed/circle-stdlib/ and ~/MiniDexed after the git clone operations has been completed but before ./build.sh

Then follow the steps as in compile-history.txt i.e. start with:

``` 
export RPI=3
git clone https://github.com/probonopd/MiniDexed
cd MiniDexed
mkdir -p kernels sdcard
git submodule update --init --recursive
sh -ex submod.sh
wget https://developer.arm.com/-/media/Files/downloads/gnu-a/10.3-2021.07/binrel/gcc-arm-10.3-2021.07-x86_64-aarch64-none-elf.tar.xz
tar xvf gcc-arm-*-*.tar.xz
export PATH=$(readlink -f ./gcc-*/bin/):$PATH
./build.sh
cp ./src/kernel*.img ./kernels/
cd ./circle-stdlib/libs/circle/boot
make
make armstub64
cd -
cd sdcard
cp ../kernels/* . || true
zip -r ../MiniDexed_$GITHUB_RUN_NUMBER_$(date +%Y-%m-%d).zip *
../getsysex.sh
cd ..
cp -r ./circle-stdlib/libs/circle/boot/* sdcard
rm -rf sdcard/config*.txt sdcard/README sdcard/Makefile sdcard/armstub sdcard/COPYING.linux
cp ./src/config.txt ./src/minidexed.ini ./src/*img ./src/performance.ini sdcard/
echo "usbspeed=full" > sdcard/cmdline.txt
``` 

The resulting unmodified sdcard folder is here as compiled-sdcard.zip, with the modified minidexed.ini for the specifiec hardware used, also here.

<p align="left">
 
 
</p>

Using exactly the same procedure under Linux Mint 21.2 also yielded a functional setup - refer to the screenshot below - and the sdcard files are in sdcard.tar.gz - compile10.txt (about 18 kilo-lines), is the complete build output during the compilation. (Replace sudo apt install zip with sudo apt install git). A Raspberry Pi 4B build was also completed using RASPPI = 4 in Make.conf - it is here as sdcard-rpi4.tar.gz.

<p align="left">
 
</p>

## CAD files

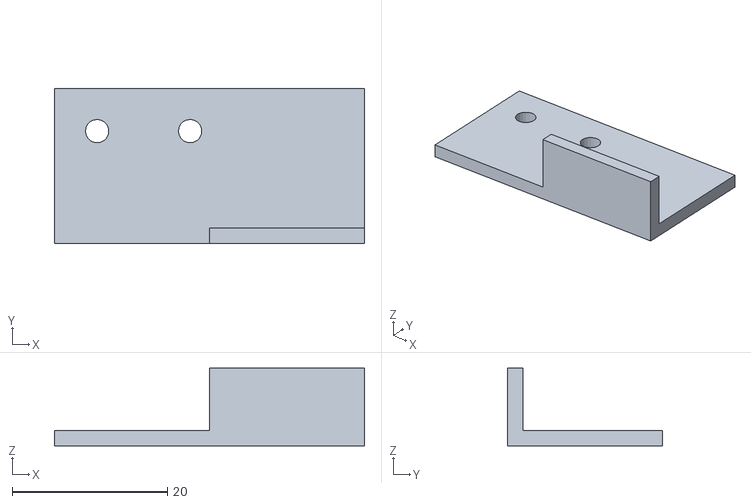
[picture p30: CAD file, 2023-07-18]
Microdexed1/STL/USB2Bracket.stl
40.0 x 20.0 x 10.0

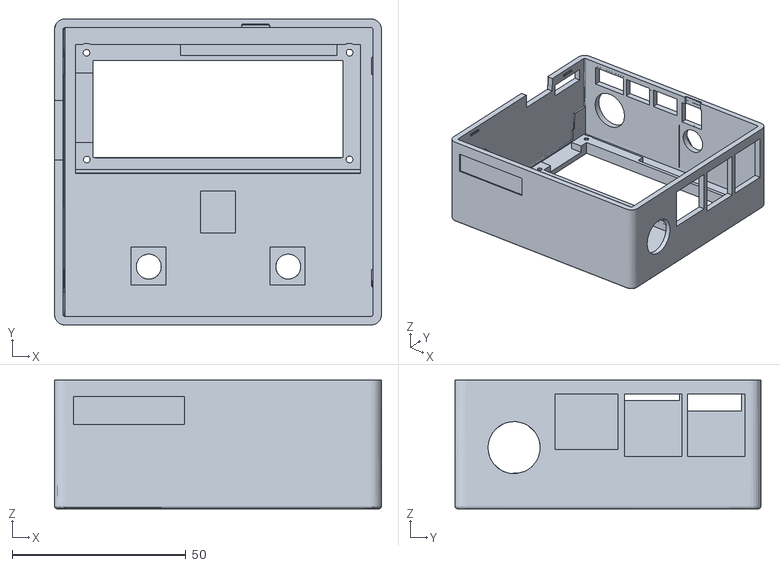
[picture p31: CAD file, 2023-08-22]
Minidexed1/STL/MinidexedCaseRPi4Top.stl
94.0 x 88.0 x 37.0

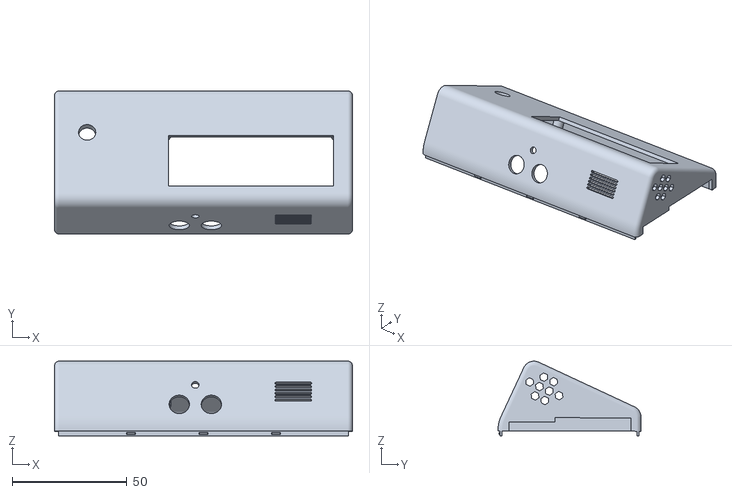
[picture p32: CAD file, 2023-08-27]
Minidexed2/STL/MiniDexedTop.stl
130.0 x 62.5 x 32.6

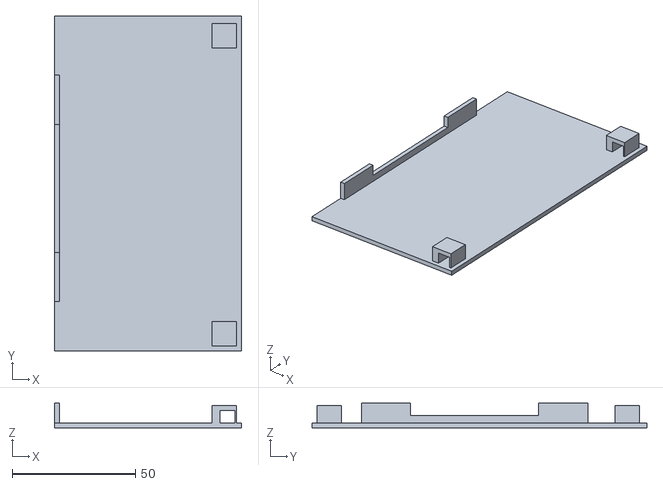
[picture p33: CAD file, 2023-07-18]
Microdexed2/STL/MicrodexedBottom5.stl
76.0 x 136.0 x 10.0

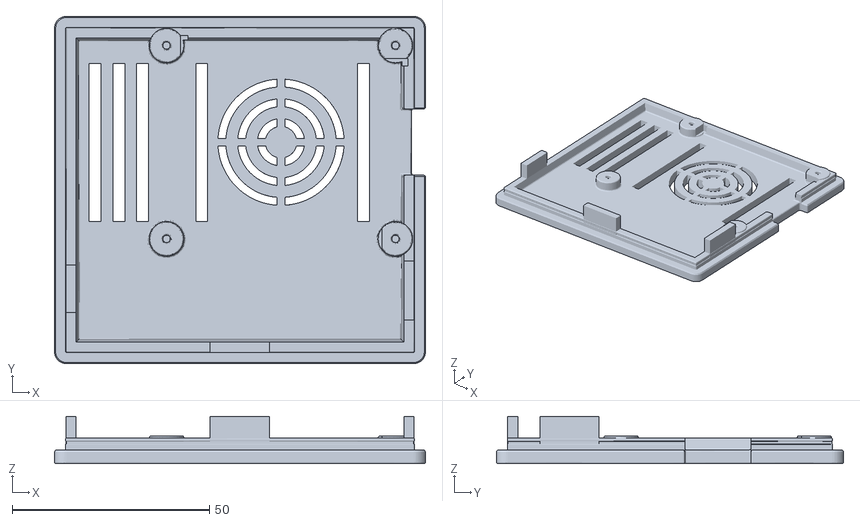
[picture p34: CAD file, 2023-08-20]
Minidexed1/STL/MinidexedCaseRPi4Bottom.stl
94.0 x 88.0 x 12.0

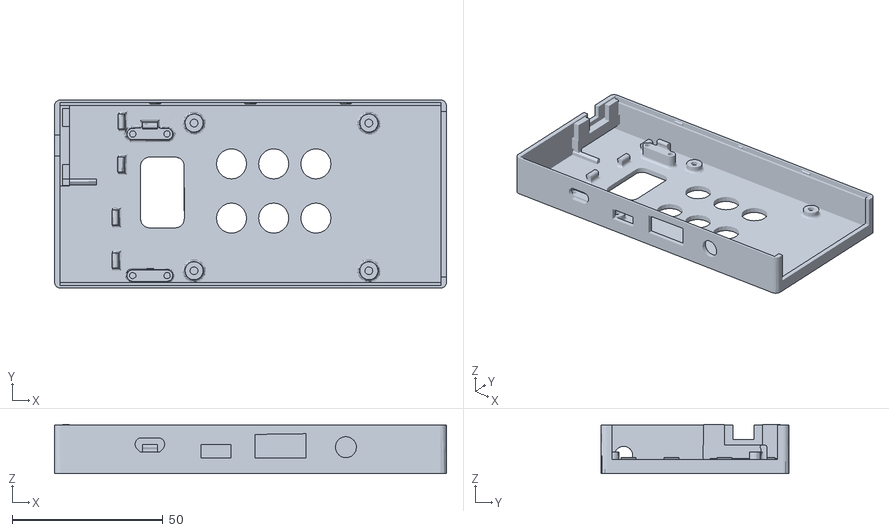
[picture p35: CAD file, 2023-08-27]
Minidexed2/STL/MiniDexedBottom.stl
130.1 x 62.5 x 16.4

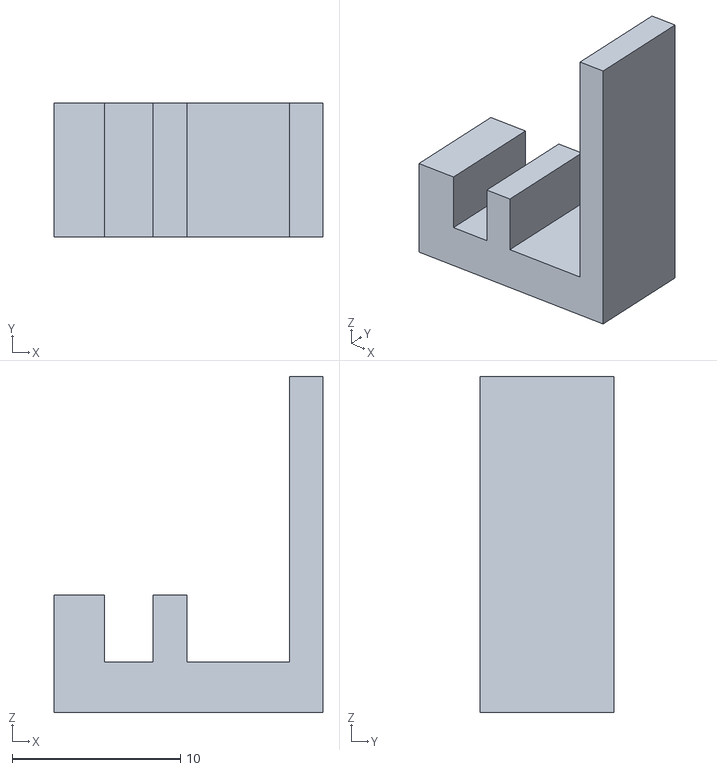
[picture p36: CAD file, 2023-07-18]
Microdexed2/STL/MicrodexedBracket1.stl
16.0 x 8.00 x 20.0

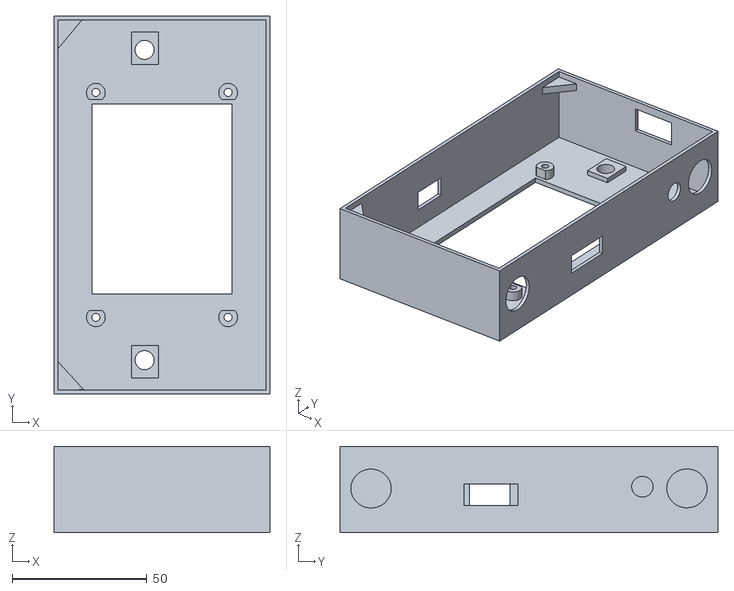
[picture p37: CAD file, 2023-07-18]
Microdexed2/STL/Microdexedbox5.stl
80.0 x 140.0 x 32.0

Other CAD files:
Minidexed1/STL/minidexedv2caseB.stl
Minidexed1/STL/minidexedv2caseT.stl
Microdexed2/STL/USB2Bracket2.stl

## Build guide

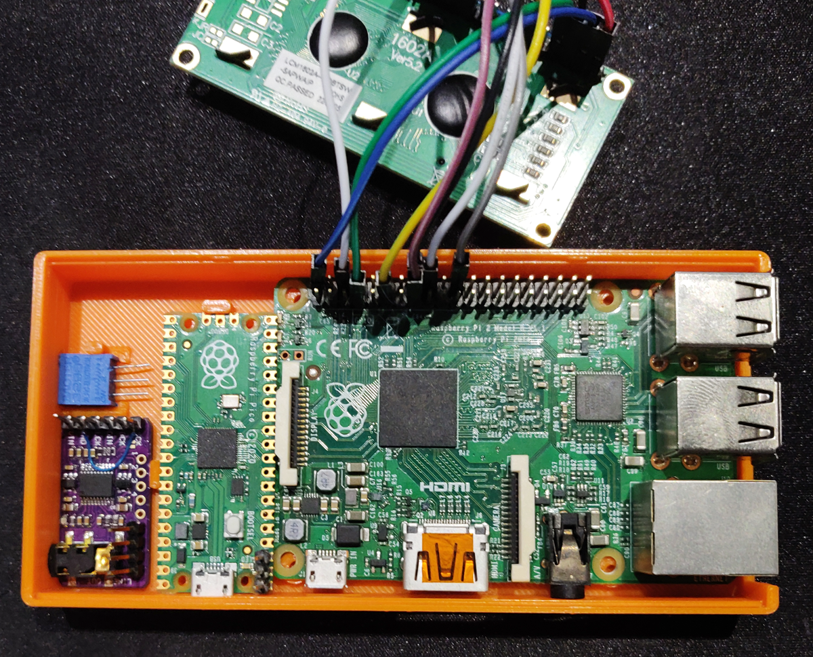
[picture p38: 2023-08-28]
Minidexed2/images/DHSbuild.png

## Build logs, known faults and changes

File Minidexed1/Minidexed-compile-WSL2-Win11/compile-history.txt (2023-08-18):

  207  export RPI=3
  208  git clone https://github.com/probonopd/MiniDexed
  209  cd MiniDexed
  210  mkdir -p kernels sdcard
  211  git submodule update --init --recursive
  212  sh -ex submod.sh
  213  wget https://developer.arm.com/-/media/Files/downloads/gnu-a/10.3-2021.07/binrel/gcc-arm-10.3-2021.07-x86_64-aarch64-none-elf.tar.xz
  214  tar xvf gcc-arm-*-*.tar.xz
  215  export PATH=$(readlink -f ./gcc-*/bin/):$PATH
  216  $PATH
  217  ls
  218  nano Config.mk
  219  ls
  220  mc
  221  ./build.sh
  222  gcc --version
  223  sudo apt-get update
  224  sudo apt-get install build-essential
  225  gcc --version
  226  ./build.sh
  227  mc
  228  cp ./src/kernel*.img ./kernels/
  229  cd ./circle-stdlib/libs/circle/boot
  230  make
  231  make armstub64
  232  cd -
  233  cd sdcard
  234  cp ../kernels/* . || true
  235  zip -r ../MiniDexed_$GITHUB_RUN_NUMBER_$(date +%Y-%m-%d).zip *
  236  sudo apt install zip
  237  zip -r ../MiniDexed_$GITHUB_RUN_NUMBER_$(date +%Y-%m-%d).zip *
  238  ../getsysex.sh
  239  cd ..
  240  cp -r ./circle-stdlib/libs/circle/boot/* sdcard
  241  rm -rf sdcard/config*.txt sdcard/README sdcard/Makefile sdcard/armstub sdcard/COPYING.linux
  242  cp ./src/config.txt ./src/minidexed.ini ./src/*img ./src/performance.ini sdcard/
  243  echo "usbspeed=full" > sdcard/cmdline.txt
  244  cd sdcard
  245  ls
  246  cd -
  247  mc
  248  history

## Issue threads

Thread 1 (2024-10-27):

Teensy 4.1 does not find Sysex folder on SD card

rolfdegen, 2024-10-27:
I use Teensy 4.1, DAC PCM5102A and LCD 2X16. I use Synth-Variation Microdexed3. Unfortunately without success. No sound. See my post on discord microdexed
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

https://discord.com/channels/1017534928616951819/1017539452589056132

TobiasVanDyk, 2024-10-28:
Hi Rolf
I remember you from your Jeannie Synth on the Teensy Forum
I would search the source code for the *ERROR* string and work back from there?
Undoubtedly it is just something to do with the SD file system
best wishes
Tobie van Dyk

TobiasVanDyk, 2024-10-28:
Also read [**here**](https://codeberg.org/positionhigh/MicroDexed-touch/issues/142)

rolfdegen, 2024-11-02:
The version with Teensy 4.0 and SD card reader (from Audio Board Rev D) and PCM5102A works. Thanks for the support.

Pic https://i.ibb.co/zN56y7V/20241031-115126.jpg

Closed 2024-11-12.

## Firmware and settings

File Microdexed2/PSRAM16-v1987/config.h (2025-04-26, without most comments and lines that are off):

#pragma once
#include <Arduino.h>
#include "midinotes.h"
#include "teensy_board_detection.h"
#include <vector>
#define DBG_LOG(s)
#include "version.h"
#if defined APC
#define APC_NUM_PADS 64
#endif
#define MIDI_DEVICE_DIN Serial1
#define MIDI_DEVICE_USB 1
#define MIDI_DEVICE_USB_HOST
#define I2S_AUDIO_ONLY // for PCM5102 or other I2S DACs
#define PSRAM  // opt. 8MB PSRAM Chip soldered to Teensy 4.1
#define DEFAULT_MIDI_CHANNEL MIDI_CHANNEL_OMNI
#define SYSEXBANK_DEFAULT 0
#define SYSEXSOUND_DEFAULT 0
#define SERIAL_SPEED 230400
#define SHOW_CPU_LOAD_MSEC 5000
#if !defined(COMPILE_FOR_PROGMEM) && !defined(COMPILE_FOR_SDCARD) && !defined(COMPILE_FOR_PSRAM)
#define COMPILE_FOR_PROGMEM // default
#endif
#ifndef CAPACITIVE_TOUCH_DISPLAY // TFT with Capacitive Touchscreen, currently for testing purposes only
#define GENERIC_DISPLAY // generic/noname ILI941 TFT + XPT2046 Touchscreen (default)
#endif
#define NUM_DEXED 4
#define DEFAULT_DEXED_MIDI_CHANNEL_INST0 1
#define DEFAULT_DEXED_MIDI_CHANNEL_INST1 2
#define DEFAULT_DEXED_MIDI_CHANNEL_INST2 3
#define DEFAULT_DEXED_MIDI_CHANNEL_INST3 4
#define NUM_DRUMS 8 // set 0 to disable Drums
#define DEFAULT_DRUM_MIDI_CHANNEL 10
#define NUM_CUSTOM_MIDI_MAPPINGS 18 // Number of Custom Key, CC and Button Mappings
#define NUM_CUSTOM_SAMPLES 20
#define NUM_STATIC_PITCHED_SAMPLES 6
#define NUM_DRUMSET_CONFIG 71 + NUM_CUSTOM_SAMPLES
#define NUM_SEQ_PATTERN 32
#define NUM_SEQ_TRACKS 8
#define SONG_LENGTH 64
#define NUM_CHAINS 32
#define NUM_EPIANO_VOICES 16
#define DEFAULT_EP_MIDI_CHANNEL 5
#define NUM_MICROSYNTH 2
#define DEFAULT_MICROSYNTH_MIDI_CHANNEL_INST0 6
#define DEFAULT_MICROSYNTH_MIDI_CHANNEL_INST1 7
#define NUM_BRAIDS 8
#define DEFAULT_BRAIDS_MIDI_CHANNEL 8
#define NUM_MULTISAMPLES 2
#define NUM_MULTISAMPLE_ZONES 8
#define DEFAULT_MSP_MIDI_CHANNEL_INST0 11
#define DEFAULT_MSP_MIDI_CHANNEL_INST1 12
#define VIRT_KEYB_YPOS 166
#define MOD_DELAY_SAMPLE_BUFFER int32_t(TIME_MS2SAMPLES(15.0)) // 15.0 ms delay buffer.
#define MOD_WAVEFORM WAVEFORM_TRIANGLE                         // WAVEFORM_SINE WAVEFORM_TRIANGLE WAVEFORM_SAWTOOTH WAVEFORM_SAWTOOTH_REVERSE
#define MOD_FILTER_OUTPUT MOD_BUTTERWORTH_FILTER_OUTPUT        // MOD_LINKWITZ_RILEY_FILTER_OUTPUT MOD_BUTTERWORTH_FILTER_OUTPUT MOD_NO_FILTER_OUTPUT
#define MOD_FILTER_CUTOFF_HZ 2000
#define byte __uint8_t // workarounds "error: reference to 'byte' is ambiguous"
#define DELAY_MAX_TIME 10000 // 10s
#define SAMPLE_RATE 44100
#define AUDIO_MEM SAMPLE_RATE *NUM_DEXED * 70 / 128000 + 36 + 14
#define COLOR_BACKGROUND 0x0000
#define COLOR_SYSTEXT 0xFFFF
#define DX_DARKCYAN 0x030D
#define COLOR_INSTR 0x7BBD
#define COLOR_CHORDS 0xE2FA
#define COLOR_ARP 0xFC80
#define COLOR_DRUMS 0xFE4F
#define COLOR_PITCHSMP 0x159A
#define RED 0xD000
#define PINK 0xF81F
#define YELLOW 0xFFEB
#define GREEN 0x07E0
#define MIDDLEGREEN 0x1500
#define DARKGREEN 0x0AE0
#define GREY1 0xC638
#define GREY2 0x52AA
#define GREY3 0x2104
#define GREY4 0x10A2
const char back_text[5] = { 'B', 'A', 'C', 'K' };
const char back_clear[5] = { ' ', ' ', ' ', ' ' };
#define TFT_WIDTH 240
#define TFT_HEIGHT 320
#define DISPLAY_WIDTH 320
#define DISPLAY_HEIGHT 240
#define display_cols 20
#define display_rows 6
#define CHAR_width 12
#define CHAR_height 17
#define CHAR_width_small 6
#define CHAR_height_small 8
#define button_size_x 7
#define button_size_y 4
#define TFT_DC 37
#define TFT_CS 41
#define TFT_RST 24
#define TFT_SCK 27
#define TFT_MISO 39
#define TFT_MOSI 26
#define TFT_TOUCH_IRQ 33
#if defined GENERIC_DISPLAY
#define TFT_TOUCH_CS 38
#endif
#define VOICE_SELECTION_MS 60000
#define BACK_FROM_VOLUME_MS 2000
#define MESSAGE_WAIT_TIME 1000
#define MIDI_DECAY_TIMER 50
#if (defined RGB_ENCODERS && defined MCP_23008) || (defined RGB_ENCODERS && defined MCP_23017)
#define RGB_LED_L_RED 0                            // MCP GPA0  = LED_ENC_L RED
#define RGB_LED_L_GREEN 1                          // MCP GPA1  = LED_ENC_L GREEN
#define RGB_LED_L_BLUE 2                           // MCP GPA2  = LED_ENC_L BLUE
#define RGB_LED_R_RED 3                            // MCP GPA3  = LED_ENC_R RED
#define RGB_LED_R_GREEN 4                          // MCP GPA4  = LED_ENC_R GREEN
#define RGB_LED_R_BLUE 5                           // MCP GPA5  = LED_ENC_R BLUE
#endif
#if (defined BUTTON_LEDS && defined MCP_23008) || (defined BUTTON_LEDS && defined MCP_23017)
#define LED_UP 8                                   // MCP GPB0  = LED Button UP
#define LED_DOWN 9                                 // MCP GPB1  = LED Button DOWN
#define LED_LEFT 10                                // MCP GPB2  = LED Button LEFT
#define LED_RIGHT 11                                // MCP GPB3  = LED Button RIGHT
#define LED_SEL 12                                  // MCP GPB4   = LED Button SEL
#define LED_START 13                                // MCP GPB5  = LED Button START
#define LED_BUT_A 14                                // MCP GPB6  = LED Button A
#define LED_BUT_B 15                                // MCP GPB7  = LED Button B
#endif
#define NUM_ENCODER 2
#define ENC_L_PIN_A 32
#define ENC_L_PIN_B 31
#define BUT_L_PIN 30
#define ENC_R_PIN_A 28
#define ENC_R_PIN_B 29
#define BUT_R_PIN 25
#define BUT_DEBOUNCE_MS 20
#define LONG_BUTTON_PRESS 500
#define AUTOSTORE_MS 5000
#define DEXED_POOLS 100
#define DEXED_CONFIG_PATH "DEXED"
#define FAV_CONFIG_PATH "FAVCFG"
#define MAX_BANKS 100
#define MAX_VOICES 32     // voices per bank
#define BANK_NAME_LEN 11  // 10 (plus '\0')
#define VOICE_NAME_LEN 12 // 11 (plus '\0')
#define FILENAME_LEN BANK_NAME_LEN + VOICE_NAME_LEN
#define CONFIG_FILENAME_LEN 50
#define FILENAME_MAX_LEN 16
#define FULLPATH_MAX_LEN 64
#define PERFORMANCE_CONFIG_PATH "PERFORMANCE"
#define SEQUENCER_CONFIG_NAME "sequencer"
#define DRUMS_CONFIG_NAME "drums"
#define DRUMS_MAPPING_NAME "drmmap"
#define PATTERN_CONFIG_NAME "patterns"
#define VELOCITY_CONFIG_NAME "velocity"
#define CHAIN_CONFIG_NAME "chain"
#define TRANSPOSE_CONFIG_NAME "transp"
#define SONG_CONFIG_NAME "song"
#define FX_CONFIG_NAME "fx"
#define VOICE_CONFIG_NAME "voice"
#define SYS_CONFIG_NAME "sys"
#define EPIANO_CONFIG_NAME "epiano"
#define MICROSYNTH_CONFIG_NAME "msynth"
#define MULTISAMPLE_PRESETS_CONFIG_NAME "msp_presets"
#define BRAIDS_CONFIG_NAME "braids"
#define MULTIBAND_CONFIG_NAME "multiband"
#define SIDECHAIN_CONFIG_NAME "sc"
#define LIVESEQUENCER_CONFIG_NAME "liveseq"
#define SAMPLES_CONFIG_NAME "samples"
#define SLICES_CONFIG_NAME "slices"
#define ENVELOPES_CONFIG_NAME "envelope"
#define MAX_PERF_MOD 50
#define MAX_FILES 150
#define PCM5102_MUTE_PIN 34 // hardware pin for PCM5102 XSMT soft mute function
#define AUDIO_DEVICE_USB
#ifdef MUSIKANDMORE
#define MCP_INTA 8
#define ANALOG_VOLUME_IN 15
#define CV_CLOCK_IN 22
#define TRS_PEDAL_IN 23
#define GEN3_CS_SDCARD_EXTERNAL 35
#endif
#define CONTROL_RATE_MS 50
#define MICROSYNTH_CONTROL_RATE_MS 30
#define BRAIDS_CONTROL_RATE_MS 30
#define SAVE_SYS_MS 5000
#define VOL_MAX_FLOAT 0.98
#define MAX_NOTES 64
#define MIDI_DECAY_LEVEL_TIME 500
#define TIME_MS2SAMPLES(x) floor(uint32_t(x) * AUDIO_SAMPLE_RATE / 1000) * sizeof(int16_t)
#define XSTR(x) STR(x)
#define STR(x) #x
#define MOD_NO_FILTER_OUTPUT 0
#define MOD_BUTTERWORTH_FILTER_OUTPUT 1
#define MOD_LINKWITZ_RILEY_FILTER_OUTPUT 2
#if defined(TEENSY_DAC_SYMMETRIC)
#define MONO_MIN 1
#define MONO_MAX 1
#define MONO_DEFAULT 1
#else
#define MONO_MIN 0
#define MONO_MAX 3
#define MONO_DEFAULT 0
#endif
#define MIDI_CONTROLLER_MODE_MAX 2
#define VOLUME_MIN 0
#define VOLUME_MAX 100
#define VOLUME_DEFAULT 80
#define PANORAMA_MIN 0
#define PANORAMA_MAX 40
#define PANORAMA_DEFAULT 20
#define MIDI_CHANNEL_MIN MIDI_CHANNEL_OMNI
#define MIDI_CHANNEL_MAX 16
#define MIDI_CHANNEL_DEFAULT MIDI_CHANNEL_OMNI
#define INSTANCE_LOWEST_NOTE_MIN 21
#define INSTANCE_LOWEST_NOTE_MAX 108
#define INSTANCE_LOWEST_NOTE_DEFAULT 21
#define INSTANCE_HIGHEST_NOTE_MIN 21
#define INSTANCE_HIGHEST_NOTE_MAX 108
#define INSTANCE_HIGHEST_NOTE_DEFAULT 108
#define CHORUS_FREQUENCY_MIN 0
#define CHORUS_FREQUENCY_MAX 100
#define CHORUS_FREQUENCY_DEFAULT 0
#define CHORUS_WAVEFORM_MIN 0
#define CHORUS_WAVEFORM_MAX 1
#define CHORUS_WAVEFORM_DEFAULT 0
#define CHORUS_DEPTH_MIN 0
#define CHORUS_DEPTH_MAX 100
#define CHORUS_DEPTH_DEFAULT 0
#define CHORUS_LEVEL_MIN 0
#define CHORUS_LEVEL_MAX 100
#define CHORUS_LEVEL_DEFAULT 0
#define DELAY_TIME_MIN 0
#define DELAY_TIME_MAX DELAY_MAX_TIME / 10
#define DELAY_TIME_DEFAULT 0
#define DELAY_FEEDBACK_MIN 0
#define DELAY_FEEDBACK_MAX 100
#define DELAY_FEEDBACK_DEFAULT 0
#define DELAY_LEVEL_MIN 0
#define DELAY_LEVEL_MAX 100
#define DELAY_LEVEL_DEFAULT 0
#define DELAY_LEVEL_GLOBAL_DEFAULT 100
#define DELAY_SYNC_MIN 0
#define DELAY_SYNC_MAX 9
#define DELAY_SYNC_DEFAULT 0
#define REVERB_ROOMSIZE_MIN 0
#define REVERB_ROOMSIZE_MAX 100
#define REVERB_ROOMSIZE_DEFAULT 0
#define REVERB_DAMPING_MIN 0
#define REVERB_DAMPING_MAX 100
#define REVERB_DAMPING_DEFAULT 0
#define REVERB_LOWPASS_MIN 0
#define REVERB_LOWPASS_MAX 100
#define REVERB_LOWPASS_DEFAULT 0
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

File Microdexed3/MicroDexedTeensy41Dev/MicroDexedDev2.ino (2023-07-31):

/*
   MicroDexed

   MicroDexed is a port of the Dexed sound engine
   Dexed ist heavily based on https://github.com/google/music-synthesizer-for-android

   (c)2018-2023 H. Wirtz <wirtz@parasitstudio.de>
   (c)2021-2022 H. Wirtz <wirtz@parasitstudio.de>, M. Koslowski <positionhigh@gmx.de>

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
   You should have received a copy of the GNU General Public License
   along with this program; if not, write to the Free Software Foundation,
   Inc., 51 Franklin Street, Fifth Floor, Boston, MA 02110-1301  USA
*/

#include <limits.h>
#include "config.h"
#include <Audio.h>
#include <Wire.h>
#include <MIDI.h>
#include <EEPROM.h>
#include <SD.h>
#include <SPI.h>
#include <TeensyVariablePlayback.h>
#include "UI.hpp"
#include "midi_devices.hpp"
#include "synth_dexed.h"
#include "dexed_sd.h"
#include <effect_modulated_delay.h>
#include <effect_stereo_mono.h>
#include <effect_mono_stereo.h>
#include <effect_platervbstereo.h>
//#include <effect_compressor.h>
#include <template_mixer.hpp>
#if NUM_DRUMS > 0
#include "midinotes.h"
#include "drumset.h"
#endif
#ifdef SGTL5000_AUDIO_ENHANCE
#include "control_sgtl5000plus.h"
#endif
#include "synth_mda_epiano.h"
#include <effect_stereo_panorama.h>
#if defined(USE_DELAY_8M)
#include <effect_delay_ext8.h>
#endif

// Audio engines
AudioSynthDexed* MicroDexed[NUM_DEXED];
AudioSynthEPiano ep(NUM_EPIANO_VOICES);

//AudioEffectCompressor2* compressor[NUM_DEXED];
AudioSynthWaveform* chorus_modulator[NUM_DEXED];
#if MOD_FILTER_OUTPUT != MOD_NO_FILTER_OUTPUT
AudioFilterBiquad* modchorus_filter[NUM_DEXED];
#endif
AudioEffectModulatedDelay* modchorus[NUM_DEXED];
AudioMixer<2>* chorus_mixer[NUM_DEXED];
AudioMixer<2>* delay_fb_mixer[NUM_DEXED];
#if defined(USE_DELAY_8M)
AudioEffectDelayExternal8* delay_fx[NUM_DEXED];
#else
AudioEffectDelay* delay_fx[NUM_DEXED];
#endif
AudioMixer<2>* delay_mixer[NUM_DEXED];
AudioEffectMonoStereo* mono2stereo[NUM_DEXED];

AudioEffectStereoPanorama ep_stereo_panorama;
AudioSynthWaveform ep_chorus_modulator;
#if MOD_FILTER_OUTPUT != MOD_NO_FILTER_OUTPUT
AudioFilterBiquad ep_modchorus_filter;
#endif
AudioEffectModulatedDelayStereo ep_modchorus;
AudioMixer<2> ep_chorus_mixer_r;
AudioMixer<2> ep_chorus_mixer_l;

AudioMixer<2> microdexed_peak_mixer;
AudioAnalyzePeak microdexed_peak;
AudioMixer<4> reverb_mixer_r;
AudioMixer<4> reverb_mixer_l;
AudioEffectPlateReverb reverb;

AudioMixer<5> master_mixer_r;
AudioMixer<5> master_mixer_l;
//AudioEffectCompressor2 compressor_r;
//AudioEffectCompressor2 compressor_l;
AudioAmplifier volume_r;
AudioAmplifier volume_l;
AudioEffectStereoMono stereo2mono;
AudioAnalyzePeak master_peak_r;
AudioAnalyzePeak master_peak_l;
#if defined(TEENSY_AUDIO_BOARD) && defined(SGTL5000_AUDIO_THRU)
AudioMixer<2> audio_thru_mixer_r;
AudioMixer<2> audio_thru_mixer_l;
#endif

// Drumset
#if NUM_DRUMS > 0
AudioPlayArrayResmp* Drum[NUM_DRUMS];
AudioMixer<NUM_DRUMS> drum_mixer_r;
AudioMixer<NUM_DRUMS> drum_mixer_l;
#if NUM_DRUMS < 5
AudioMixer<4> drum_reverb_send_mixer_r;
AudioMixer<4> drum_reverb_send_mixer_l;
#else
AudioMixer<8> drum_reverb_send_mixer_r;
AudioMixer<8> drum_reverb_send_mixer_l;
#endif
#endif

// Outputs
#if defined(TEENSY_AUDIO_BOARD)
AudioOutputI2S i2s1;
#if defined(SGTL5000_AUDIO_ENHANCE)
AudioControlSGTL5000Plus sgtl5000;
#else
AudioControlSGTL5000 sgtl5000;
#endif
#elif defined(I2S_AUDIO_ONLY)
AudioOutputI2S i2s1;
#elif defined(TGA_AUDIO_BOARD)
AudioOutputI2S i2s1;
AudioControlWM8731master wm8731_1;
#elif defined(PT8211_AUDIO)
AudioOutputPT8211 pt8211_1;
#elif defined(TEENSY_DAC_SYMMETRIC)
AudioOutputAnalogStereo dacOut;
AudioMixer<4> invMixer;
#elif defined(TEENSY_DAC)
AudioOutputAnalogStereo dacOut;
#endif
#ifdef AUDIO_DEVICE_USB
AudioOutputUSB usb1;
#endif

#if defined(TEENSY_AUDIO_BOARD) && defined(SGTL5000_AUDIO_THRU)
AudioInputI2S i2s1in;
#endif

//
// Static patching of audio objects
//
AudioConnection patchCord[] = {
  // Audio chain tail
  { reverb_mixer_r, 0, reverb, 0 },
  { reverb_mixer_l, 0, reverb, 1 },
  { reverb, 0, master_mixer_r, MASTER_MIX_CH_REVERB },
  { reverb, 1, master_mixer_l, MASTER_MIX_CH_REVERB },
//  { master_mixer_r, compressor_r },
//  { master_mixer_l, compressor_l },
//  { compressor_r, volume_r },
//  { compressor_l, volume_l },
  { master_mixer_r, volume_r },
  { master_mixer_l, volume_l },
  { volume_r, 0, stereo2mono, 0 },
  { volume_l, 0, stereo2mono, 1 },
  { stereo2mono, 0, master_peak_r, 0 },
  { stereo2mono, 0, master_peak_l, 0 },

// Outputs
#if defined(TEENSY_AUDIO_BOARD)
#ifndef SGTL5000_AUDIO_THRU
  { stereo2mono, 0, i2s1, 0 },
  { stereo2mono, 1, i2s1, 1 },
#endif
#elif defined(I2S_AUDIO_ONLY)
  { stereo2mono, 0, i2s1, 0 },
  { stereo2mono, 1, i2s1, 1 },
#elif defined(TGA_AUDIO_BOARD)
  { stereo2mono, 0, i2s1, 0 },
  { stereo2mono, 1, i2s1, 1 },
#elif defined(PT8211_AUDIO)
  { stereo2mono, 0, pt8211_1, 0 },
  { stereo2mono, 1, pt8211_1, 1 },
#elif defined(TEENSY_DAC_SYMMETRIC)
  { stereo2mono, 0, dacOut, 0 },
  { stereo2mono, 1, invMixer, 0 },
  { invMixer, 0, dacOut, 1 },
#elif defined(TEENSY_DAC)
  { stereo2mono, 0, dacOut, 0 },
  { stereo2mono, 1, dacOut, 1 },
#endif
#ifdef AUDIO_DEVICE_USB
  { stereo2mono, 0, usb1, 0 },
  { stereo2mono, 1, usb1, 1 },
#endif

#if defined(TEENSY_AUDIO_BOARD) && defined(SGTL5000_AUDIO_THRU)
  { stereo2mono, 0, audio_thru_mixer_r, 0 },
  { stereo2mono, 1, audio_thru_mixer_l, 0 },
  { i2s1in, 0, audio_thru_mixer_r, 1 },
  { i2s1in, 1, audio_thru_mixer_l, 1 },
  { audio_thru_mixer_r, 0, i2s1, 0 },
  { audio_thru_mixer_l, 0, i2s1, 1 },
#endif

#if NUM_DRUMS > 0
  { drum_reverb_send_mixer_r, 0, reverb_mixer_r, REVERB_MIX_CH_DRUMS },
  { drum_reverb_send_mixer_l, 0, reverb_mixer_l, REVERB_MIX_CH_DRUMS },
  { drum_mixer_r, 0, master_mixer_r, MASTER_MIX_CH_DRUMS },
  { drum_mixer_l, 0, master_mixer_l, MASTER_MIX_CH_DRUMS },
#endif

  { ep, 0, ep_stereo_panorama, 0 },
  { ep, 1, ep_stereo_panorama, 1 },
  { ep_stereo_panorama, 0, ep_chorus_mixer_r, 0 },
  { ep_stereo_panorama, 1, ep_chorus_mixer_l, 0 },
  { ep_stereo_panorama, 0, ep_modchorus, 0 },
  { ep_stereo_panorama, 1, ep_modchorus, 1 },
#if MOD_FILTER_OUTPUT != MOD_NO_FILTER_OUTPUT
  { ep_chorus_modulator, 0, ep_modchorus_filter, 0 },
  { ep_modchorus_filter, 0, ep_modchorus, 2 },
#else
  { ep_chorus_modulator, 0, ep_modchorus, 2 },
#endif
  { ep_modchorus, 0, ep_chorus_mixer_r, 1 },
  { ep_modchorus, 1, ep_chorus_mixer_l, 1 },
  { ep_chorus_mixer_r, 0, reverb_mixer_r, REVERB_MIX_CH_EPIANO },
  { ep_chorus_mixer_l, 0, reverb_mixer_l, REVERB_MIX_CH_EPIANO },
  { ep_chorus_mixer_r, 0, master_mixer_r, MASTER_MIX_CH_EPIANO },
  { ep_chorus_mixer_l, 0, master_mixer_l, MASTER_MIX_CH_EPIANO },
};

//
// Dynamic patching of MicroDexed objects
//
uint8_t nDynamic = 0;
#if MOD_FILTER_OUTPUT != MOD_NO_FILTER_OUTPUT
AudioConnection* dynamicConnections[NUM_DEXED * 18 + NUM_DRUMS * 4];
#elif MOD_FILTER_OUTPUT == MOD_NO_FILTER_OUTPUT
AudioConnection* dynamicConnections[NUM_DEXED * 17 + NUM_DRUMS * 4];
#endif
FLASHMEM void create_audio_dexed_chain(uint8_t instance_id) {
  MicroDexed[instance_id] = new AudioSynthDexed(MAX_NOTES / NUM_DEXED, SAMPLE_RATE);
  //compressor[instance_id] = new AudioEffectCompressor2();
  mono2stereo[instance_id] = new AudioEffectMonoStereo();
  chorus_modulator[instance_id] = new AudioSynthWaveform();
#if MOD_FILTER_OUTPUT != MOD_NO_FILTER_OUTPUT
  modchorus_filter[instance_id] = new AudioFilterBiquad();
#endif
  modchorus[instance_id] = new AudioEffectModulatedDelay();
  chorus_mixer[instance_id] = new AudioMixer<2>();
  delay_fb_mixer[instance_id] = new AudioMixer<2>();
#if defined(USE_DELAY_8M)
  delay_fx[instance_id] = new AudioEffectDelayExternal8(AUDIO_MEMORY8_EXTMEM, DELAY_MAX_TIME);
#else
  delay_fx[instance_id] = new AudioEffectDelay();
#endif
  delay_mixer[instance_id] = new AudioMixer<2>();

  //dynamicConnections[nDynamic++] = new AudioConnection(*MicroDexed[instance_id], 0, *compressor[instance_id], 0);
  //dynamicConnections[nDynamic++] = new AudioConnection(*compressor[instance_id], 0, microdexed_peak_mixer, instance_id);
  //dynamicConnections[nDynamic++] = new AudioConnection(*compressor[instance_id], 0, *chorus_mixer[instance_id], 0);
  //dynamicConnections[nDynamic++] = new AudioConnection(*compressor[instance_id], 0, *modchorus[instance_id], 0);
  dynamicConnections[nDynamic++] = new AudioConnection(*MicroDexed[instance_id], 0, microdexed_peak_mixer, instance_id);
  dynamicConnections[nDynamic++] = new AudioConnection(*MicroDexed[instance_id], 0, *chorus_mixer[instance_id], 0);
  dynamicConnections[nDynamic++] = new AudioConnection(*MicroDexed[instance_id], 0, *modchorus[instance_id], 0);

#if MOD_FILTER_OUTPUT != MOD_NO_FILTER_OUTPUT
  dynamicConnections[nDynamic++] = new AudioConnection(*chorus_modulator[instance_id], 0, *modchorus_filter[instance_id], 0);
  dynamicConnections[nDynamic++] = new AudioConnection(*modchorus_filter[instance_id], 0, *modchorus[instance_id], 1);
#else
  dynamicConnections[nDynamic++] = new AudioConnection(*chorus_modulator[instance_id], 0, *modchorus[instance_id], 1);
#endif
  dynamicConnections[nDynamic++] = new AudioConnection(*modchorus[instance_id], 0, *chorus_mixer[instance_id], 1);
  dynamicConnections[nDynamic++] = new AudioConnection(*chorus_mixer[instance_id], 0, *delay_fb_mixer[instance_id], 0);
  dynamicConnections[nDynamic++] = new AudioConnection(*chorus_mixer[instance_id], 0, *delay_mixer[instance_id], 0);
  dynamicConnections[nDynamic++] = new AudioConnection(*delay_fb_mixer[instance_id], 0, *delay_fx[instance_id], 0);
  dynamicConnections[nDynamic++] = new AudioConnection(*delay_fx[instance_id], 0, *delay_fb_mixer[instance_id], 1);
  dynamicConnections[nDynamic++] = new AudioConnection(*delay_fx[instance_id], 0, *delay_mixer[instance_id], 1);
  dynamicConnections[nDynamic++] = new AudioConnection(*delay_mixer[instance_id], 0, *mono2stereo[instance_id], 0);
  dynamicConnections[nDynamic++] = new AudioConnection(*mono2stereo[instance_id], 0, reverb_mixer_r, instance_id);
  dynamicConnections[nDynamic++] = new AudioConnection(*mono2stereo[instance_id], 1, reverb_mixer_l, instance_id);

  dynamicConnections[nDynamic++] = new AudioConnection(*mono2stereo[instance_id], 0, master_mixer_r, instance_id);
  dynamicConnections[nDynamic++] = new AudioConnection(*mono2stereo[instance_id], 1, master_mixer_l, instance_id);

#ifdef DEBUG
  Serial.print(F("Dexed-Instance: "));
  Serial.println(instance_id);
#endif
}

//
// Dynamic patching of Drum objects
//
#if NUM_DRUMS > 0
FLASHMEM void create_audio_drum_chain(uint8_t instance_id) {
  //Drum[instance_id] = new AudioPlayMemory();
  Drum[instance_id] = new AudioPlayArrayResmp();
  Drum[instance_id]->enableInterpolation(false);
  Drum[instance_id]->setPlaybackRate(1.0);

  dynamicConnections[nDynamic++] = new AudioConnection(*Drum[instance_id], 0, drum_mixer_r, instance_id);
  dynamicConnections[nDynamic++] = new AudioConnection(*Drum[instance_id], 0, drum_mixer_l, instance_id);
  dynamicConnections[nDynamic++] = new AudioConnection(*Drum[instance_id], 0, drum_reverb_send_mixer_r, instance_id);
  dynamicConnections[nDynamic++] = new AudioConnection(*Drum[instance_id], 0, drum_reverb_send_mixer_l, instance_id);
}
#endif

// other global vars
uint8_t sd_card = 0;
Sd2Card card;
SdVolume volume;
const float midi_ticks_factor[10] = { 0.0, 0.25, 0.375, 0.5, 0.75, 1.0, 1.5, 2.0, 3.0, 4.0 };
uint8_t midi_bpm_counter = 0;
uint8_t midi_bpm = 0;
int16_t _midi_bpm = -1;
elapsedMillis midi_bpm_timer;
elapsedMillis long_button_pressed;
elapsedMillis control_rate;
elapsedMillis led_blink;
elapsedMillis save_sys;
bool led_status = false;
bool save_sys_flag = false;
uint8_t active_voices[NUM_DEXED];
uint8_t midi_voices[NUM_DEXED];
#ifdef SHOW_CPU_LOAD_MSEC
elapsedMillis cpu_mem_millis;
#endif
uint8_t midi_learn_mode = MIDI_LEARN_MODE_OFF;
uint32_t cpumax = 0;
uint32_t peak_dexed = 0;
float peak_dexed_value = 0.0;
uint32_t peak_r = 0;
uint32_t peak_l = 0;
config_t configuration;
const uint8_t cs_pins[] = { SDCARD_TEENSY_CS_PIN, SDCARD_AUDIO_CS_PIN };
const uint8_t mosi_pins[] = { SDCARD_TEENSY_MOSI_PIN, SDCARD_AUDIO_MOSI_PIN };
const uint8_t sck_pins[] = { SDCARD_TEENSY_SCK_PIN, SDCARD_AUDIO_SCK_PIN };
char version_string[LCD_cols + 1];
char sd_string[LCD_cols + 1];
char g_voice_name[NUM_DEXED][VOICE_NAME_LEN];
char g_bank_name[NUM_DEXED][BANK_NAME_LEN];
char receive_bank_filename[FILENAME_LEN];
uint8_t selected_instance_id = 0;
uint8_t active_sample = 0;
int8_t midi_decay[NUM_DEXED] = { -1, -1 };
elapsedMillis midi_decay_timer;
int perform_attack_mod[NUM_DEXED] = { 0, 0 };
int perform_release_mod[NUM_DEXED] = { 0, 0 };
// Allocate the delay lines for chorus
int16_t* delayline[NUM_DEXED];
int16_t* ep_delayline_r;
int16_t* ep_delayline_l;
uint8_t midinote_old[NUM_DRUMSET_CONFIG];

#if NUM_DRUMS > 0
//extern drum_config_t drum_config[NUM_DRUMSET_CONFIG];
uint8_t drum_counter;
uint8_t drum_type[NUM_DRUMS];
#endif

extern LCDMenuLib2 LCDML;

extern void getNoteName(char* noteName, uint8_t noteNumber);

/***********************************************************************
   SETUP
 ***********************************************************************/
void setup() {
#ifdef DEBUG
  Serial.begin(SERIAL_SPEED);
#else
  delay(50);  // seems to be needed when no serial debugging is enabled
#endif

  setup_ui();
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
void loop() {
  // MIDI input handling
  check_midi_devices();

  // check encoder
  ENCODER[ENC_L].update();
  ENCODER[ENC_R].update();

  LCDML.loop();

  // CONTROL-RATE-EVENT-HANDLING
  if (control_rate > CONTROL_RATE_MS) {
    control_rate = 0;

    // check for value changes, unused voices and CPU overload
    for (uint8_t instance_id = 0; instance_id < NUM_DEXED; instance_id++) {
      active_voices[instance_id] = MicroDexed[instance_id]->getNumNotesPlaying();
      if (active_voices[instance_id] == 0)
        midi_voices[instance_id] = 0;
    }

    if (LCDML.FUNC_getID() == LCDML.OTHER_getIDFromFunction(UI_func_voice_select)) {
      for (uint8_t instance_id = 0; instance_id < NUM_DEXED; instance_id++) {
#if defined(ARDUINO_TEENSY40) || defined(ARDUINO_TEENSY41)
        if (midi_decay_timer > MIDI_DECAY_TIMER && midi_decay[instance_id] > 0) {
          midi_decay[instance_id]--;
          display.createChar(6 + instance_id, (uint8_t*)special_chars[15 - (7 - midi_decay[instance_id])]);
          display.setCursor(14 + instance_id, 1);
          display.write(6 + instance_id);
        } else if (midi_voices[instance_id] == 0 && midi_decay[instance_id] == 0 && !MicroDexed[instance_id]->getSustain()) {
          midi_decay[instance_id]--;
          display.setCursor(14 + instance_id, 1);
          display.write(20);  // blank
        }
#else
        static bool midi_playing[NUM_DEXED];
        if (midi_voices[instance_id] > 0 && midi_playing[instance_id] == false) {
          midi_playing[instance_id] = true;
          display.setCursor(14 + instance_id, 1);
          display.write(6 + instance_id);
        } else if (midi_voices[instance_id] == 0 && !MicroDexed[instance_id]->getSustain()) {
          midi_playing[instance_id] = false;
          display.setCursor(14 + instance_id, 1);
          display.write(20);  // blank
        }
#endif
      }
#if defined(ARDUINO_TEENSY40) || defined(ARDUINO_TEENSY41)
      if (midi_decay_timer > MIDI_DECAY_LEVEL_TIME) {
        midi_decay_timer = 0;
      }
#endif
    }
  } else
    yield();

  // SAVE-SYS-EVENT-HANDLING
  if (save_sys > SAVE_SYS_MS && save_sys_flag == true) {
#ifdef DEBUG
    Serial.println(F("Check if we can save configuration.sys"));
#endif
    bool instance_is_playing = false;
    for (uint8_t instance_id = 0; instance_id < NUM_DEXED; instance_id++) {
      if (active_voices[instance_id] > 0) {
        instance_is_playing = true;
        break;
      }
    }
    if (instance_is_playing == false) {
      for (uint8_t instance_id = 0; instance_id < NUM_DRUMS; instance_id++) {
        if (Drum[instance_id]->isPlaying()) {
          instance_is_playing = true;
          break;
        }
      }
    }
    if (instance_is_playing == false)
      save_sd_sys_json();
    else {
#ifdef DEBUG
      Serial.println(F("System is playing, next try..."));
#endif
      save_sys = 0;
    }
  }

#if defined(DEBUG) && defined(SHOW_CPU_LOAD_MSEC)
  if (cpu_mem_millis >= SHOW_CPU_LOAD_MSEC) {
    if (master_peak_r.available())
      if (master_peak_r.read() == 1.0)
        peak_r++;
    if (master_peak_l.available())
      if (master_peak_l.read() == 1.0)
        peak_l++;
    if (microdexed_peak.available()) {
      peak_dexed_value = microdexed_peak.read();
      if (peak_dexed_value > 0.99)
        peak_dexed++;
    }
    cpu_mem_millis -= SHOW_CPU_LOAD_MSEC;
    show_cpu_and_mem_usage();
  }
#endif

  // LED blink
  if (led_blink > LED_BLINK_MS) {
    digitalWrite(LED_BUILTIN, led_status);
    led_status = !led_status;
    led_blink = 0;
  }
}

/******************************************************************************
  MIDI HELPER
******************************************************************************/
bool checkMidiChannel(byte inChannel, uint8_t instance_id) {
  // check for MIDI channel
  if (configuration.dexed[instance_id].midi_channel == MIDI_CHANNEL_OMNI) {
    return (true);
  } else if (inChannel != configuration.dexed[instance_id].midi_channel) {
#ifdef DEBUG
    Serial.print(F("INSTANCE "));
    Serial.print(instance_id, DEC);
    Serial.print(F(": Ignoring MIDI data on channel "));
    Serial.print(inChannel);
    Serial.print(F("(listening on "));
    Serial.print(configuration.dexed[instance_id].midi_channel);
    Serial.println(F(")"));
#endif
    return (false);
  }
  return (true);
}

void init_MIDI_send_CC(void) {
#ifdef DEBUG
  Serial.println(F("init_MIDI_send_CC():"));
#endif
  MD_sendControlChange(configuration.dexed[selected_instance_id].midi_channel, 7, configuration.dexed[selected_instance_id].sound_intensity);
  MD_sendControlChange(configuration.dexed[selected_instance_id].midi_channel, 10, configuration.dexed[selected_instance_id].pan);
  MD_sendControlChange(configuration.dexed[selected_instance_id].midi_channel, 91, configuration.fx.reverb_send[selected_instance_id]);
  MD_sendControlChange(configuration.dexed[selected_instance_id].midi_channel, 93, configuration.fx.chorus_level[selected_instance_id]);
  MD_sendControlChange(configuration.dexed[selected_instance_id].midi_channel, 94, configuration.dexed[selected_instance_id].tune);
  MD_sendControlChange(configuration.dexed[selected_instance_id].midi_channel, 103, configuration.fx.filter_resonance[selected_instance_id]);
  MD_sendControlChange(configuration.dexed[selected_instance_id].midi_channel, 104, configuration.fx.filter_cutoff[selected_instance_id]);
  MD_sendControlChange(configuration.dexed[selected_instance_id].midi_channel, 105, configuration.fx.delay_time[selected_instance_id]);
  MD_sendControlChange(configuration.dexed[selected_instance_id].midi_channel, 106, configuration.fx.delay_feedback[selected_instance_id]);
  MD_sendControlChange(configuration.dexed[selected_instance_id].midi_channel, 107, configuration.fx.delay_level[selected_instance_id]);
}

/******************************************************************************
  MIDI MESSAGE HANDLER
******************************************************************************/
void handleNoteOn(byte inChannel, byte inNumber, byte inVelocity) {
  //
  // MIDI learn mode
  //
  if (midi_learn_mode > MIDI_LEARN_MODE_OFF) {
    int8_t tmp_channel = handle_midi_learn(inNumber);
    if (tmp_channel >= 0)
      inChannel = tmp_channel;
  }

  //
  // Play Notes
  //

  // MicroDexed
  for (uint8_t instance_id = 0; instance_id < NUM_DEXED; instance_id++) {
    if (checkMidiChannel(inChannel, instance_id)) {
      if (inNumber >= configuration.dexed[instance_id].lowest_note && inNumber <= configuration.dexed[instance_id].highest_note) {
        if (configuration.dexed[instance_id].polyphony > 0) {
          MicroDexed[instance_id]->keydown(inNumber, uint8_t(float(configuration.dexed[instance_id].velocity_level / 127.0) * inVelocity + 0.5));
          midi_voices[instance_id]++;
        }
#if defined(ARDUINO_TEENSY40) || defined(ARDUINO_TEENSY41)
        if (LCDML.FUNC_getID() == LCDML.OTHER_getIDFromFunction(UI_func_voice_select)) {
          midi_decay_timer = 0;
          midi_decay[instance_id] = min(inVelocity / 5, 7);
        }
#endif
#ifdef DEBUG
        char note_name[4];
        getNoteName(note_name, inNumber);
        Serial.print(F("KeyDown "));
        Serial.print(inNumber);
        Serial.print(F("/"));
        Serial.print(note_name);
        Serial.print(F(" instance "));
        Serial.print(instance_id, DEC);
        Serial.print(F(" MIDI-channel "));
        Serial.println(inChannel, DEC);
        Serial.flush();
#endif
      }
    }
  }

  // E-Piano
  if (configuration.epiano.midi_channel == MIDI_CHANNEL_OMNI || configuration.epiano.midi_channel == inChannel) {
    if (inNumber >= configuration.epiano.lowest_note && inNumber <= configuration.epiano.highest_note) {
      ep.noteOn(inNumber + configuration.epiano.transpose - 24, inVelocity);
#ifdef DEBUG
      char note_name[4];
      getNoteName(note_name, inNumber);
      Serial.print(F("KeyDown "));
      Serial.print(inNumber);
      Serial.print(F("/"));
      Serial.print(note_name);
      Serial.print(F(" EPIANO "));
      Serial.print(F(" MIDI-channel "));
      Serial.println(inChannel, DEC);
      Serial.flush();
#endif
    }
  }

  // Drums
#if NUM_DRUMS > 0
  if (inChannel == configuration.drums.midi_channel || configuration.drums.midi_channel == MIDI_CHANNEL_OMNI) {
    if (drum_counter >= NUM_DRUMS)
      drum_counter = 0;

    if (midi_learn_mode > MIDI_LEARN_MODE_OFF) {
      inNumber = configuration.drums.midinote[active_sample];
    }
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

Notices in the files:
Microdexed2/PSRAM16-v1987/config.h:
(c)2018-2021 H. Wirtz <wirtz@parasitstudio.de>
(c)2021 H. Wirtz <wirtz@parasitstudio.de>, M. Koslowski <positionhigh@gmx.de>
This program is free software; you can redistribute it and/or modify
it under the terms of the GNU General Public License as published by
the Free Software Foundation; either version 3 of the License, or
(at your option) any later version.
